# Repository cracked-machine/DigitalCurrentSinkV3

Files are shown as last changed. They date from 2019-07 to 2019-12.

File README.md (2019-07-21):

# Digital Current Sink Ver3

[Control Module Interactive BOM](https://cracked-machine.github.io/DigitalCurrentSinkV3/HW/ControlModule/doc/IBOM/ibom.html)

[Current Sink Module Interactive BOM](https://cracked-machine.github.io/DigitalCurrentSinkV3/HW/CurrentSinkModule/CurrentSinkModule/docs/IBOM/ibom.html)

[SMPS Module Interactive BOM](https://cracked-machine.github.io/DigitalCurrentSinkV3/HW/IsolatedThreeOutputSMPS/ExternRegulatedConverters/ExternRegulatedConverter_12D_12S_5S/docs/IBOM/ibom.html)

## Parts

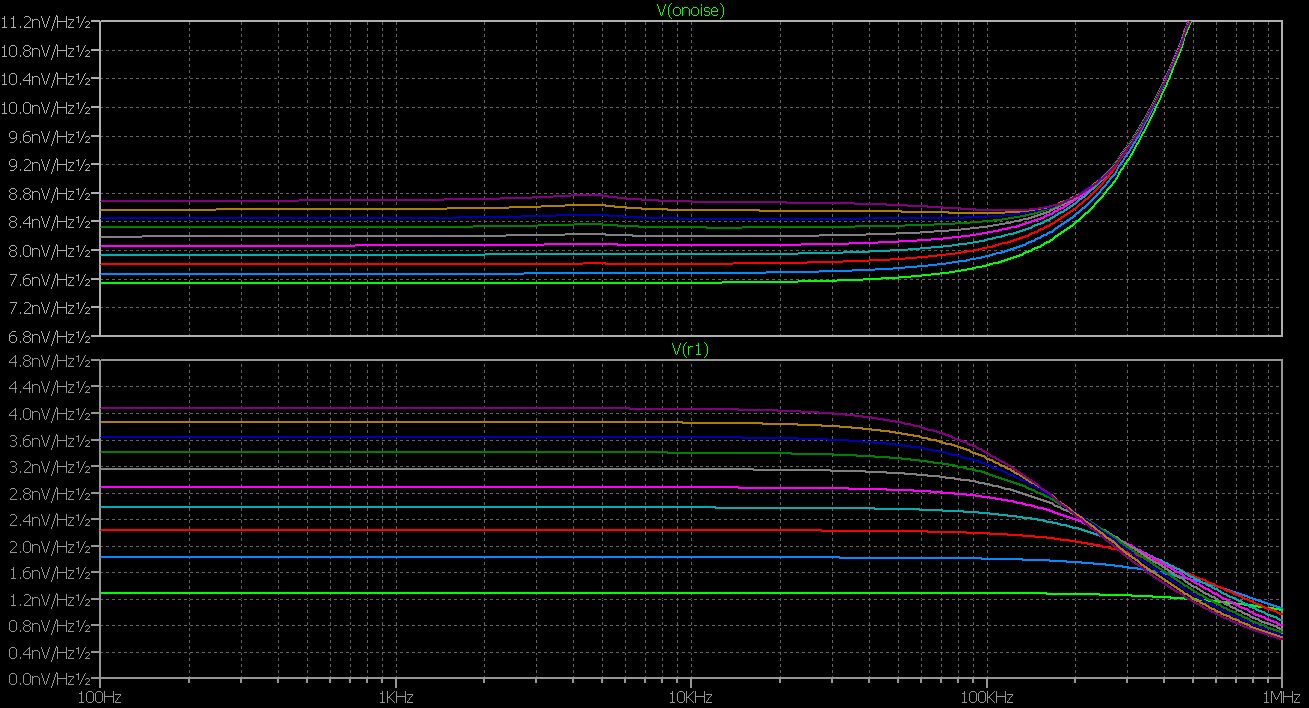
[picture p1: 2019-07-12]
HW/Simulation/ADA4522/FirstOrderSK_LowPass/1stOrderLowsPass_NoiseRange100R_1K.png

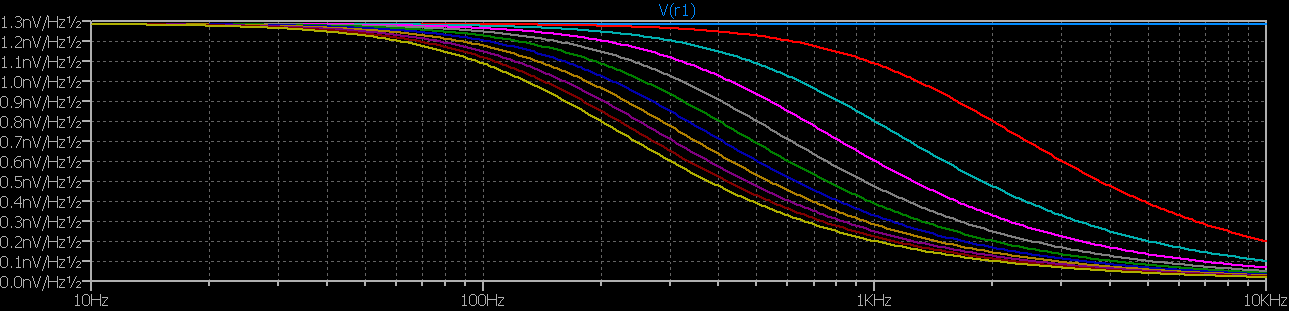
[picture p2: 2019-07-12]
HW/Simulation/ADA4522/FirstOrderSK_LowPass/1stOrderLowsPass_NoiseAndAttentuation100R_10u.png

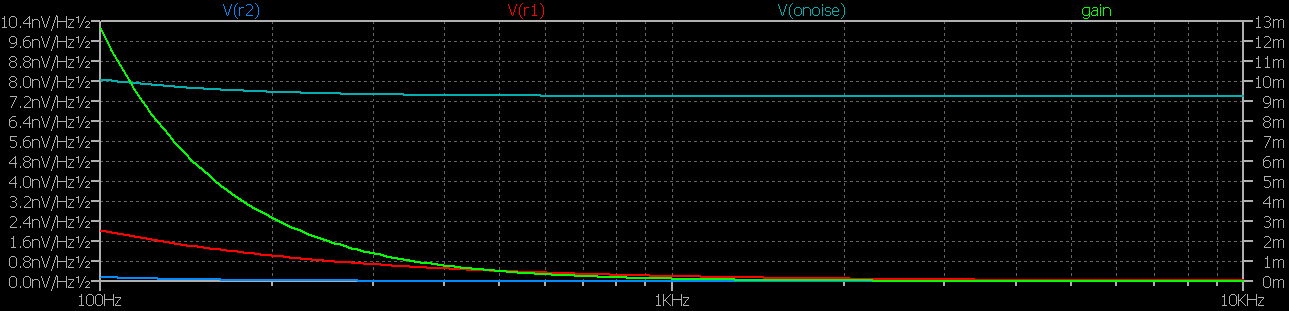
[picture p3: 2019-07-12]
HW/Simulation/ADA4522/SecondOrderSK_LowPass/2ndOrderSKLowPass_NoiseAndAtten_10K_1u.png

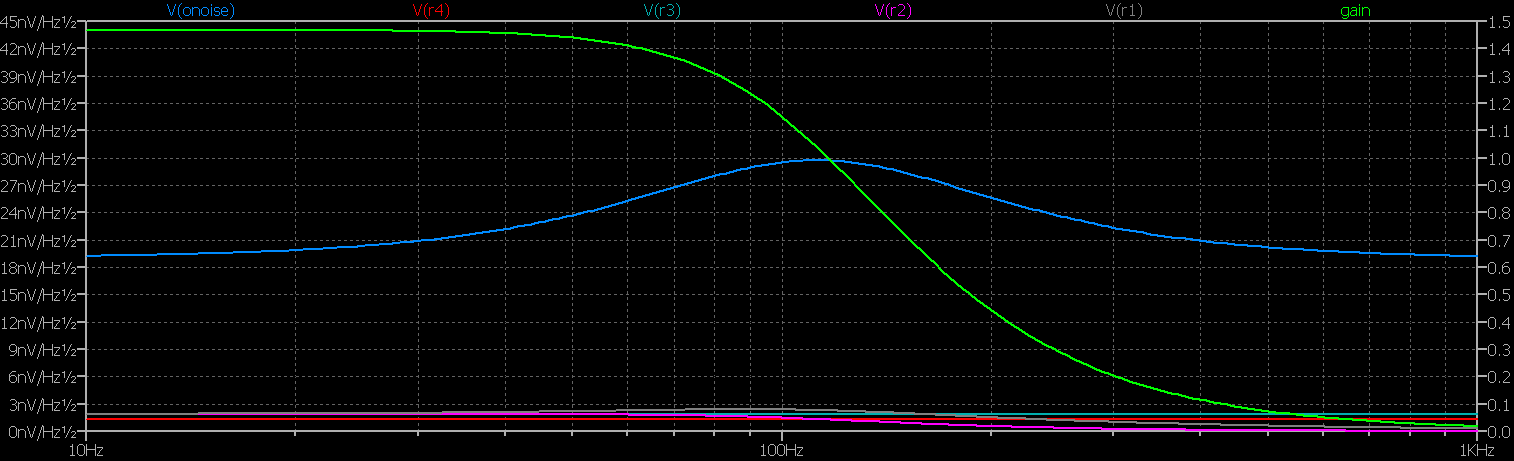
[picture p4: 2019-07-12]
HW/Simulation/LTC2058/2ndOrderSK_LowPassWithSeperateGainStage/2ndOrderLowsPass_SepStage1.5GainAndNoise2x100RWith10u_AndResistorNoiseContributions.png

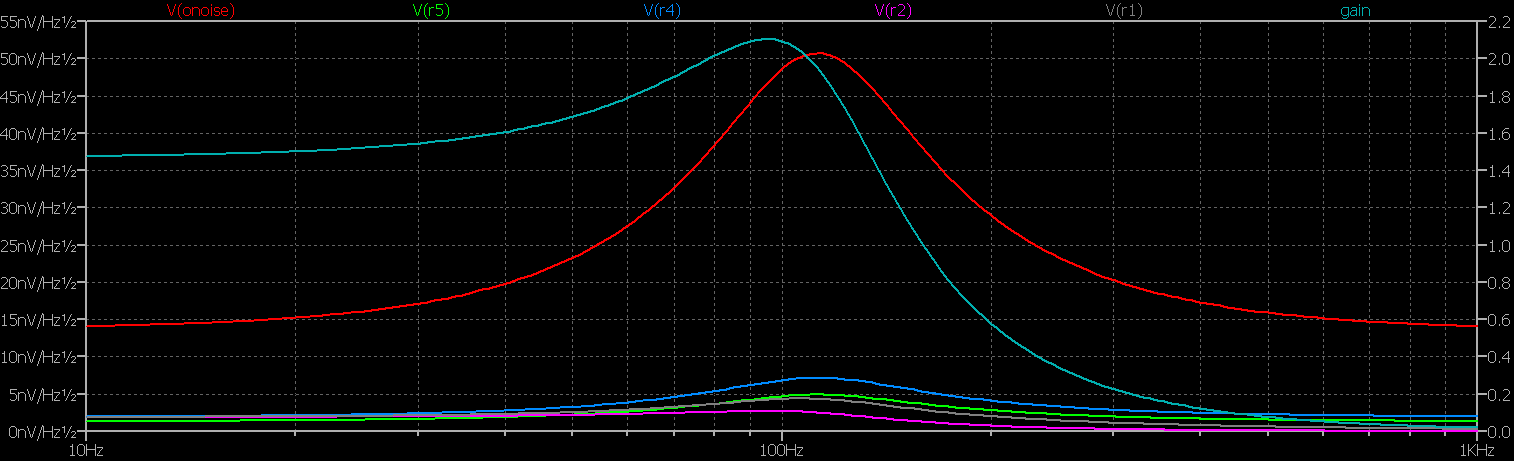
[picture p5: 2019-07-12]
HW/Simulation/LTC2058/SecondOrderSK_LowPass/2ndOrderLowsPass_1.5GainAndNoise2x100RWith10u_AndResistorNoiseContributions.png

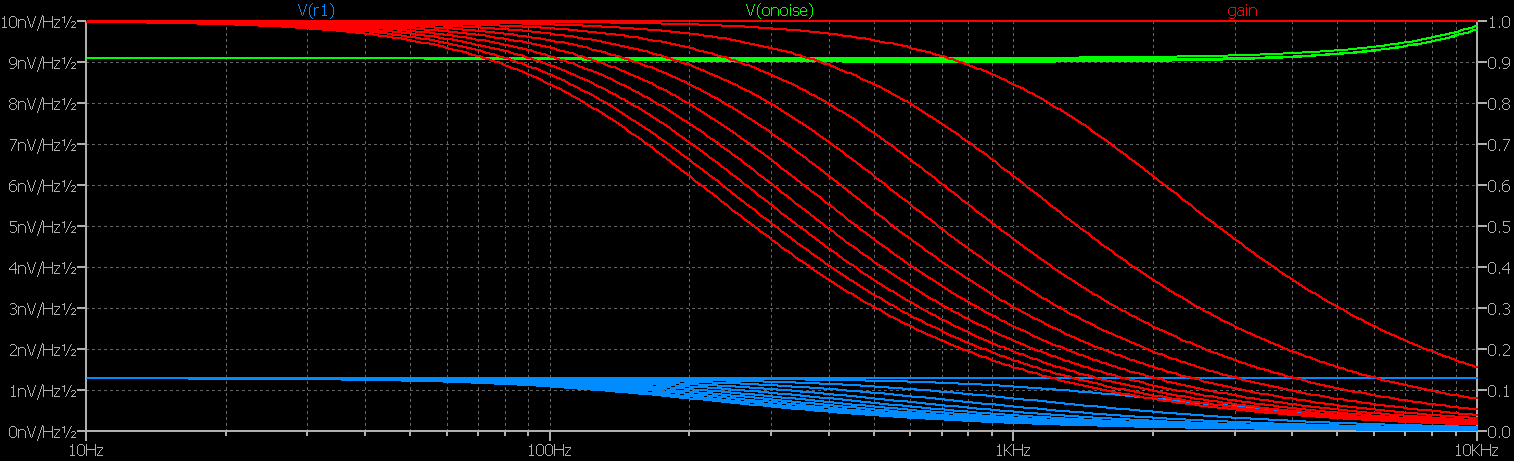
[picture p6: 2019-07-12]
HW/Simulation/LTC2058/FirstOrderSK_LowPass/1stOrderLowsPass_Noise100RWith0_10u.png

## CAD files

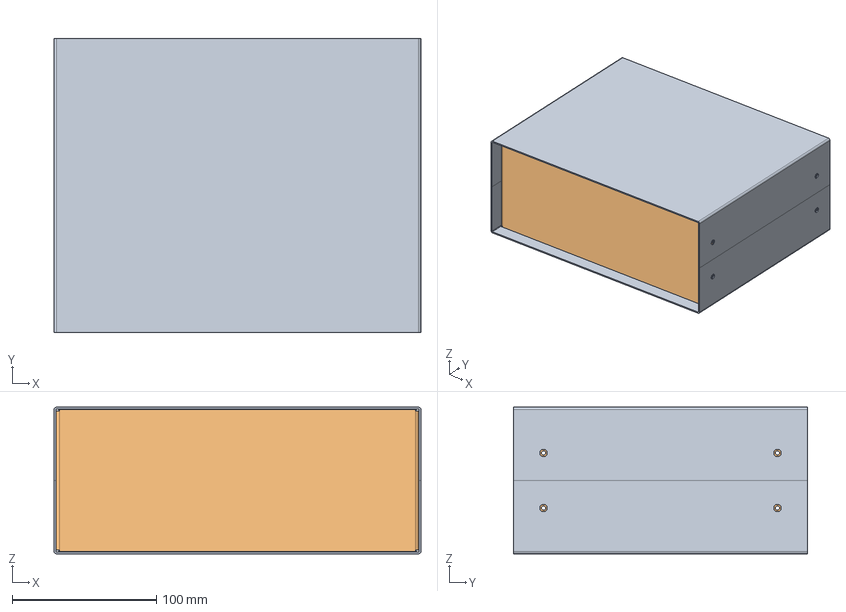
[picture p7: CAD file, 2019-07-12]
HW/Enclosure/1458G4.stp
254.0 x 203.2 x 101.6 mm

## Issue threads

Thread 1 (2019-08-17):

Molex Micro-Fit 3.0 connectors wired backwards on CurrentSink Module

cracked-machine, 2019-08-17:
For now the polarity can be switched for testing on the RevC board.

The connector footprint should be rotated 180deg on the RevD version.

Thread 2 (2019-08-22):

CurrentSink pcb heatsink "EndPlate" mounting holes should be replaced

cracked-machine, 2019-08-22:
Since the main heat-sink is to be reduced in length (100mm --> 75mm) the mounting holes on the currentsink pcb serve no purpose.

The new design is to use individual (two) heat-sinks for the complimentary MOSFETs.  Therefore, new mounting holes should be added to the currentsink pcb layout.  New heatsinks to be used are:

Fischer Elektronik SK 481/25 SA
https://docs-emea.rs-online.com/webdocs/0f3d/0900766b80f3d603.pdf

Requirements:
1) Each heatsink should have two mounting NPTH holes
2) There should be adequate clearance (air gap) from the other heatsinks to ensure electrical isolation
3) The heatsink should not touch any traces on the PCB. If necessary, traces should be moved to the other side of the PCB (see other issue)

cracked-machine, 2019-08-23:
Not required if issue #4 is implemented

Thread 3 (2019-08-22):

Move currentsink traces to back side of PCB to make room for heatsink

cracked-machine, 2019-08-22:
On currentsink layout, nets J4-Pad1 and J3_Pad3 should be moved from the front pcb side to the back pcb side. This will ensure that high current traces cannot come into accidental contact with heatsinks (see issue #2)

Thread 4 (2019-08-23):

Redesign current sink pcb for pmos/nmos to share single "LAM 3 K 75 12" heatsink

cracked-machine, 2019-08-23:
Current "SK 481/25 SA" heatsinks have 5.5K/W Rth each.
"LAM 3 K 75 12" heatsink has 1.1K/W.

Would also require moving the power connector "JPWR1"

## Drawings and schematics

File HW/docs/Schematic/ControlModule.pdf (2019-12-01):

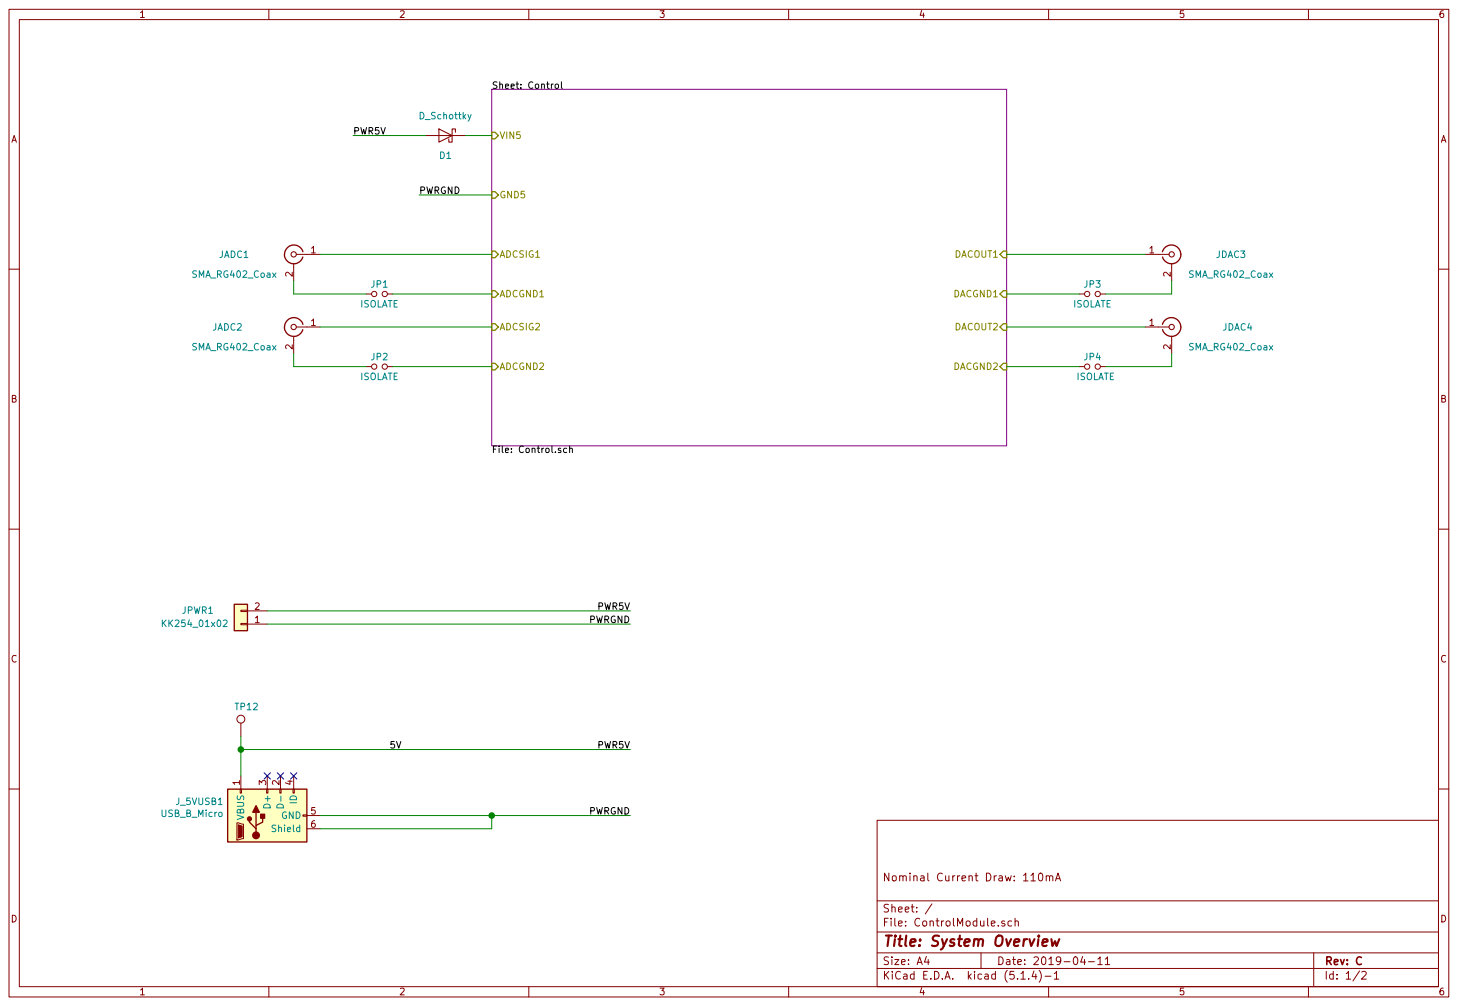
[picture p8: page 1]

File: ControlModule.sch Sheet: / Nominal Current Draw: 110mA

Id: 1/2 Title: System Overview

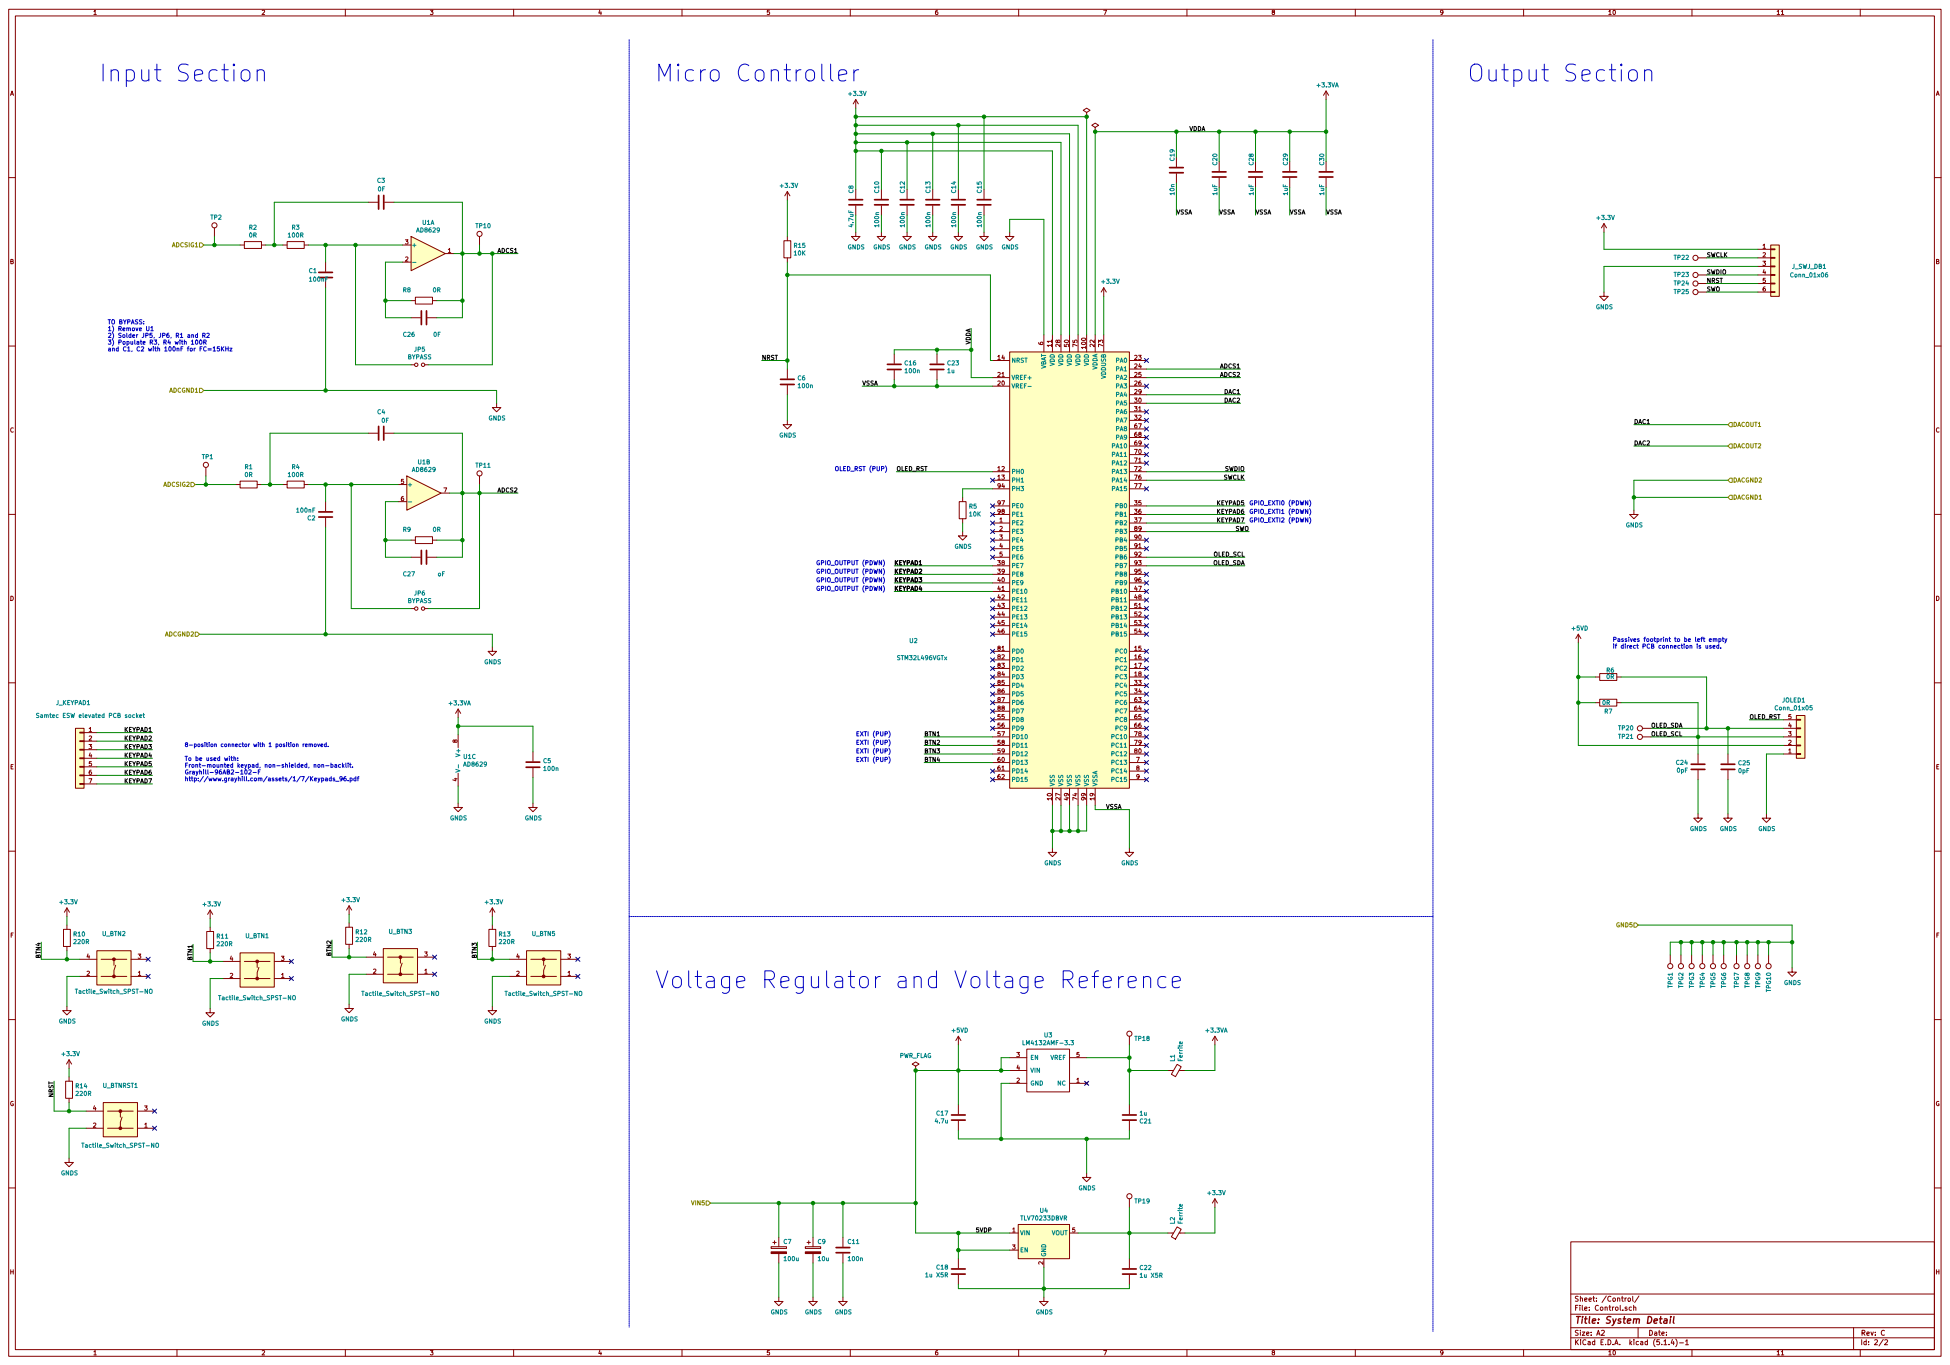
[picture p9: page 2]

6 VDD 100 VDD 11 VDD 28 VDD 50 VDD 75 VDDA 22 VDDUSB 73 VREF+ 21 VREF- 20 VSS 10 VSS 27 VSS 49 VSS 74 VSS 99 VSSA 19 U2 STM32L496VGTx

if direct PCB connection is used. Voltage Regulator and Voltage Reference

8-position connector with 1 position removed. To be used with: Front-mounted keypad, non-shielded, non-backlit.

Grayhill-96AB2-102-F
http://www.grayhill.com/assets/1/7/Keypads_96.pdf

Id: 2/2 Title: System Detail File: Control.sch Sheet: /Control/

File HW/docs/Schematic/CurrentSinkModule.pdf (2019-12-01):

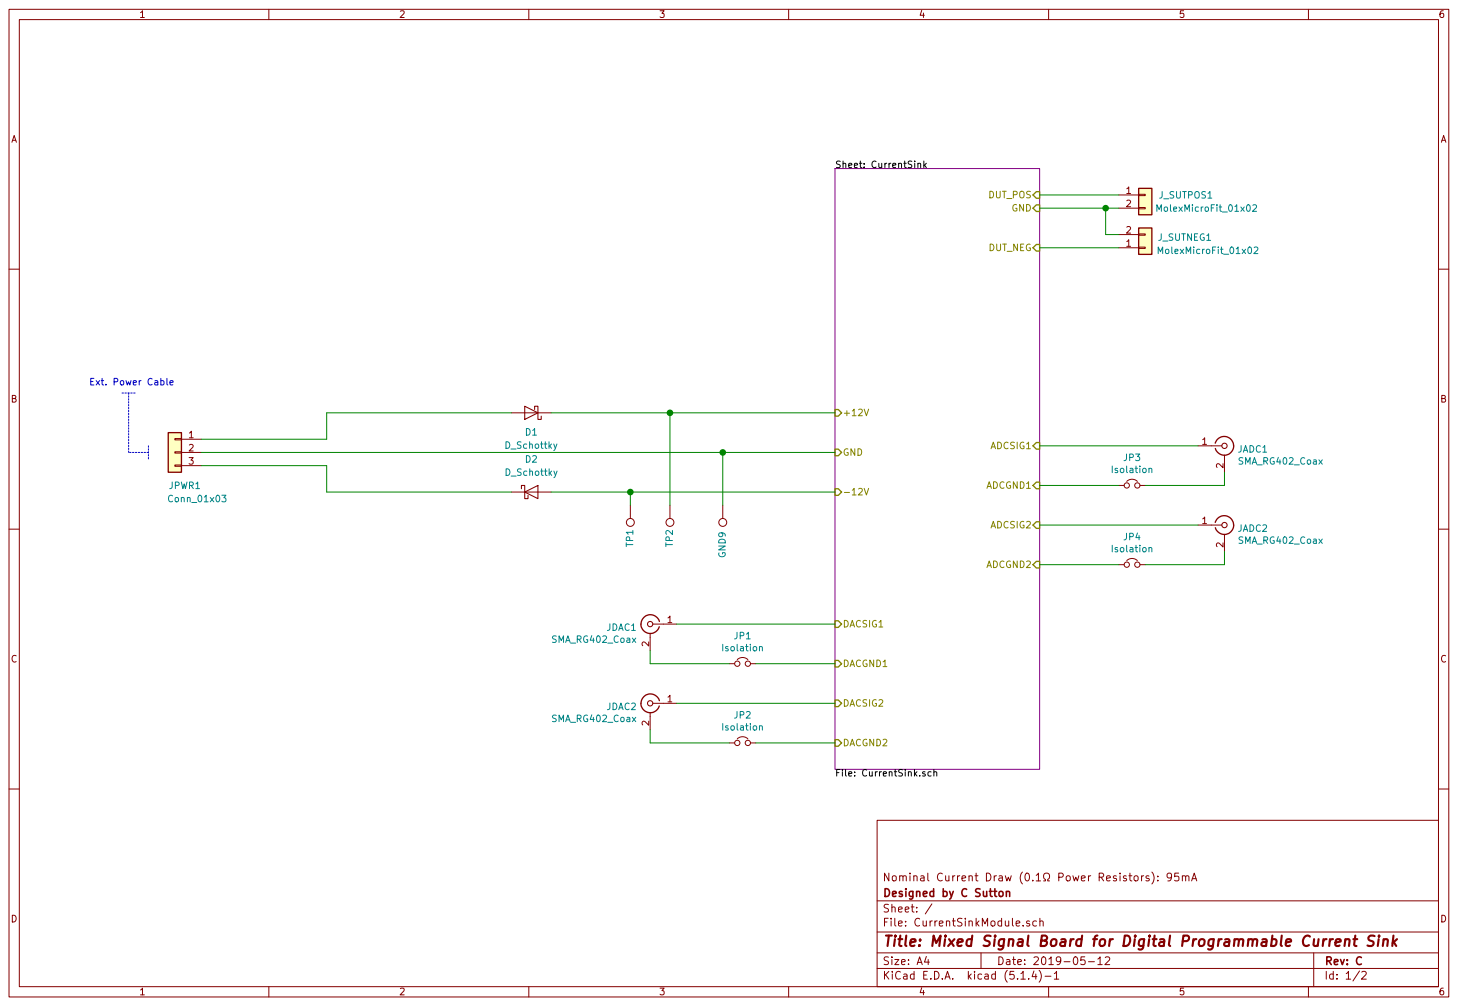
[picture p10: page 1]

ADCSIG2 ADCSIG1 ADCGND1 ADCGND2 DACSIG1 DACSIG2 DACGND1 DACGND2 +12V
File: CurrentSink.sch GND

Nominal Current Draw (0.1 Power Resistors): 95mA
File: CurrentSinkModule.sch Sheet: / Designed by C Sutton

Id: 1/2 Title: Mixed Signal Board for Digital Programmable Current Sink

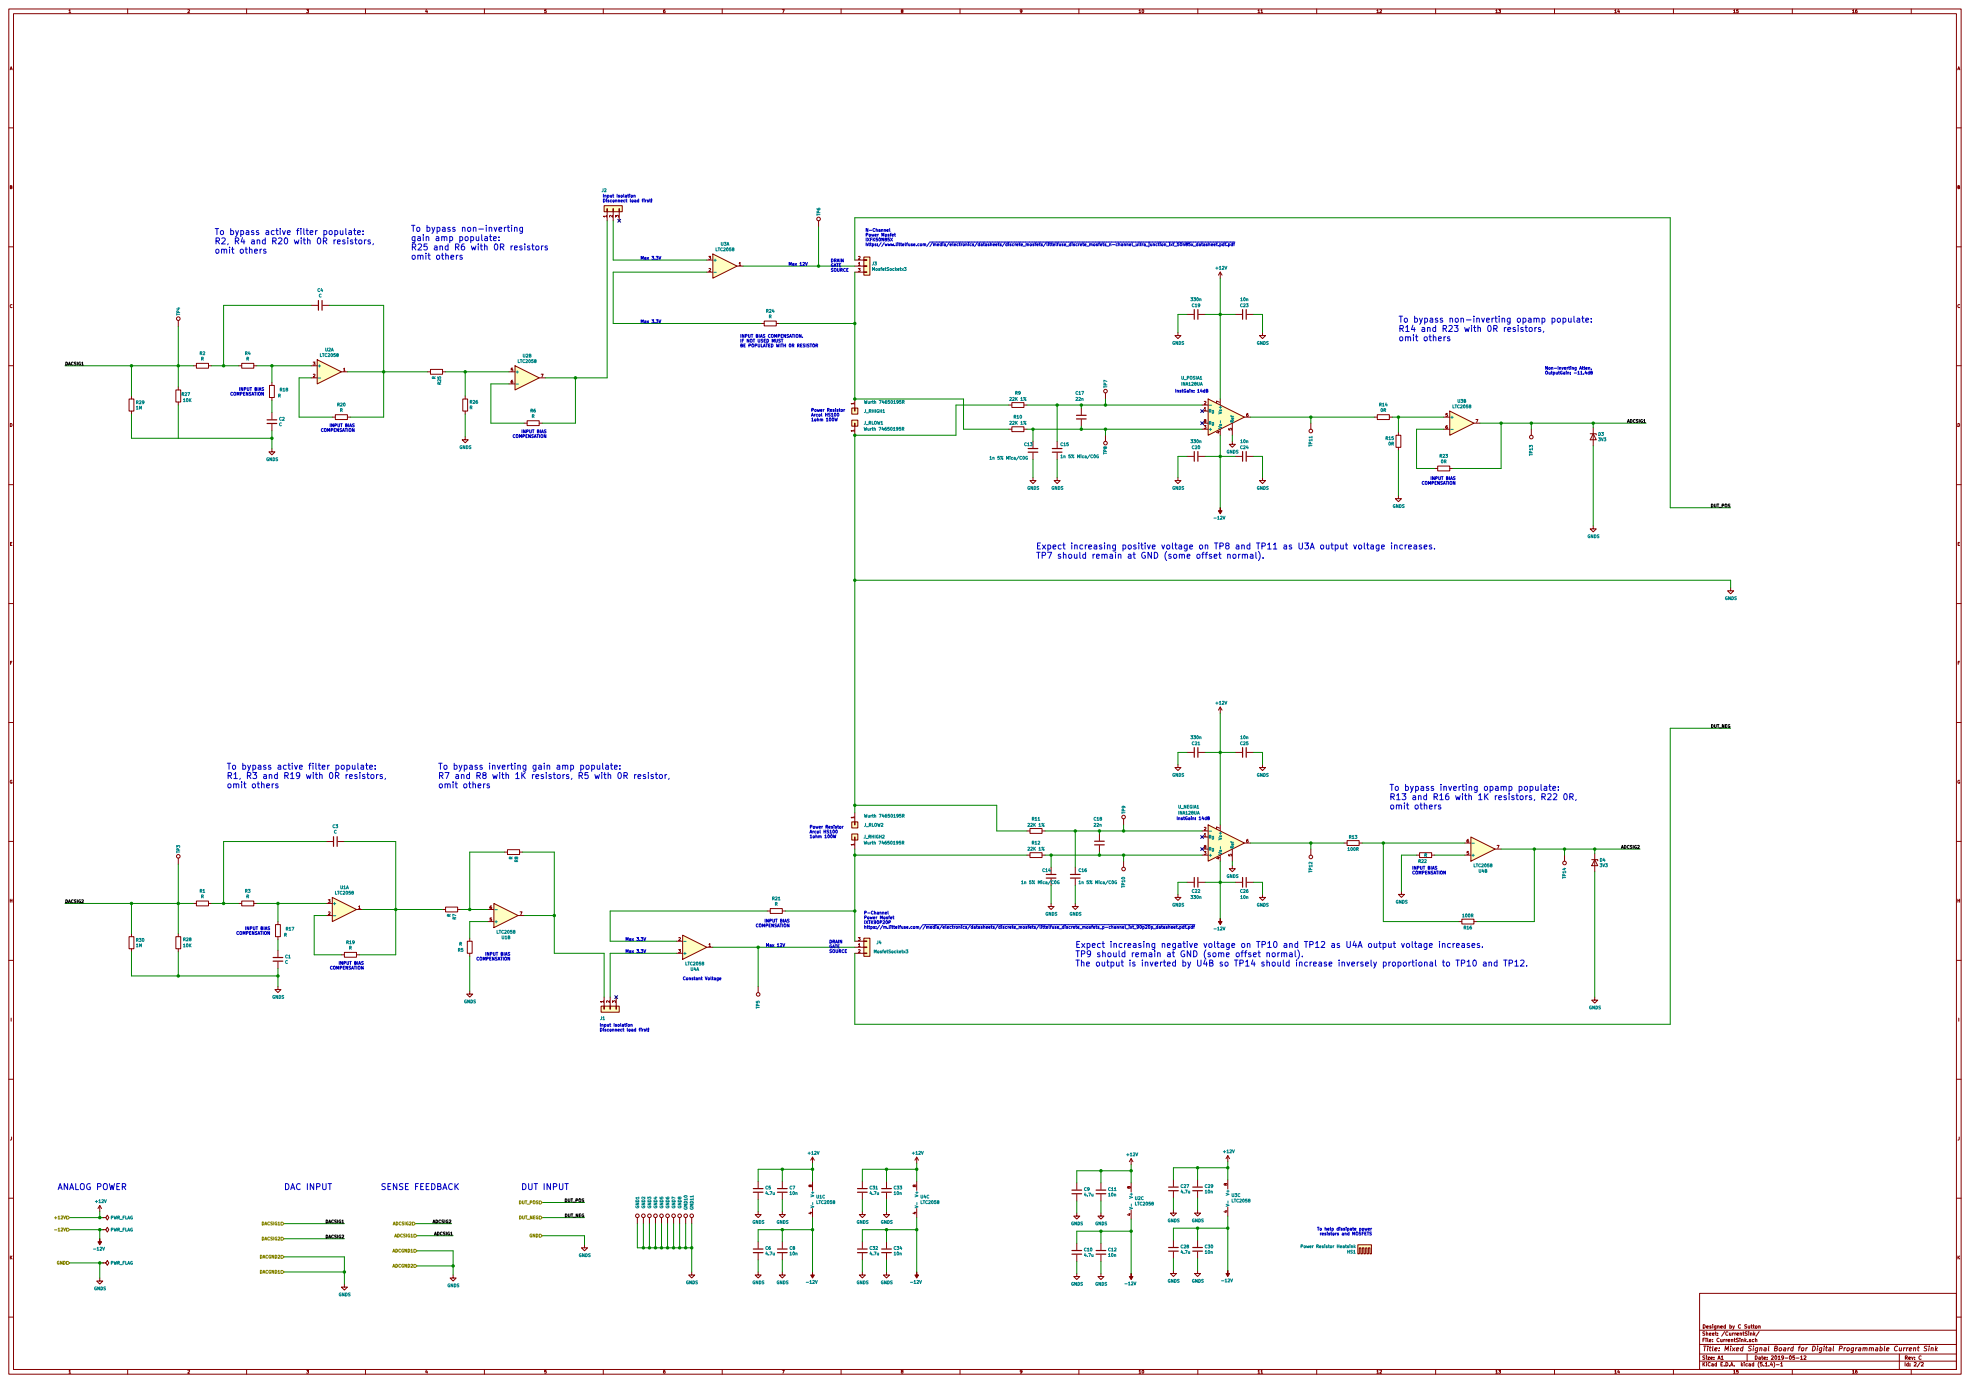
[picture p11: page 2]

Input Isolation Disconnect load first!

SOURCE To bypass active filter populate:
R2, R4 and R20 with 0R resistors,
omit others

To bypass non-inverting
gain amp populate:
R25 and R6 with 0R resistors

https://www.littelfuse.com//media/electronics/datasheets/discrete_mosfets/littelfuse_discrete_mosfets_n-channel_ultra_junction_ixf_50n85x_datasheet.pdf.pdf Power Resistor Arcol HS100 1ohm 100W

To bypass non-inverting opamp populate:
R14 and R23 with 0R resistors,

INPUT BIAS COMPENSATION.
IF NOT USED MUST BE POPULATED WITH 0R RESISTOR

File: CurrentSink.sch Sheet: /CurrentSink/ Designed by C Sutton TP8 C17

TP7 should remain at GND (some offset normal).

To bypass active filter populate:
R1, R3 and R19 with 0R resistors,

To bypass inverting gain amp populate:
R7 and R8 with 1K resistors, R5 with 0R resistor,

To bypass inverting opamp populate:
R13 and R16 with 1K resistors, R22 0R,

https://m.littelfuse.com//media/electronics/datasheets/discrete_mosfets/littelfuse_discrete_mosfets_p-channel_ixt_90p20p_datasheet.pdf.pdf Max 12V Max 3.3V Max 3.3V

Expect increasing negative voltage on TP10 and TP12 as U4A output voltage increases.
TP9 should remain at GND (some offset normal).
The output is inverted by U4B so TP14 should increase inversely proportional to TP10 and TP12.

To help dissipate power
resistors and MOSFETS

Id: 2/2 Title: Mixed Signal Board for Digital Programmable Current Sink

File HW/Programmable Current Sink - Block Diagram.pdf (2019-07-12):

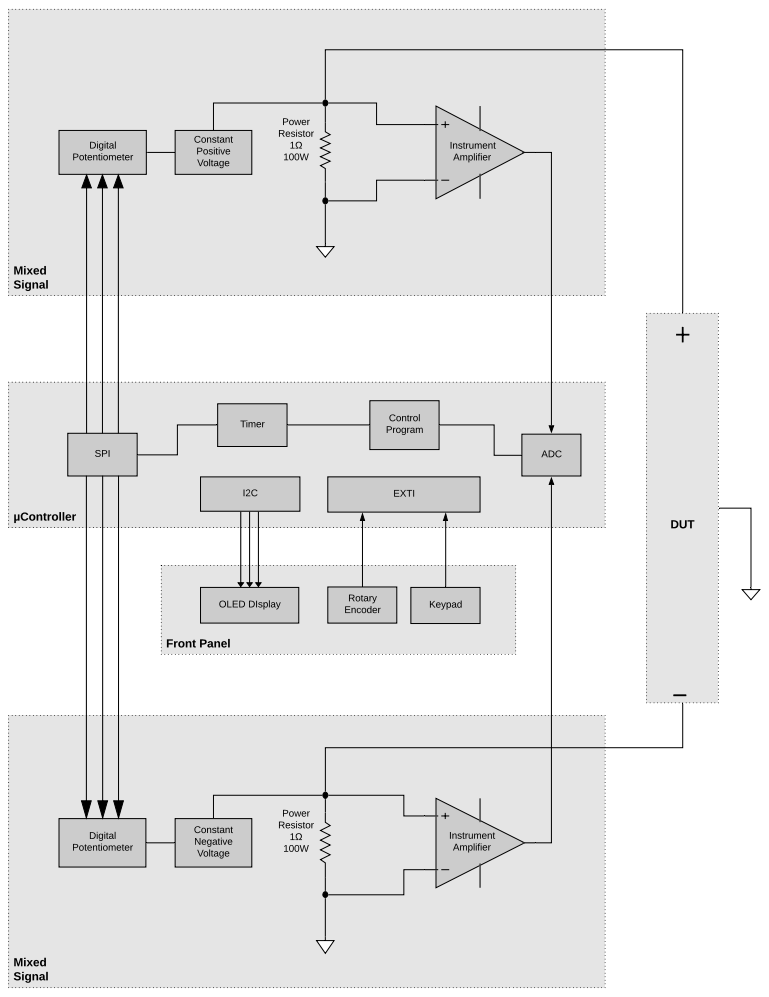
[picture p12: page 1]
Front Panel; Mixed Signal; DUT; µController; SPI; ADC; Timer; Control Program; Digital Potentiometer; Constant Negative Voltage; Power Resistor 1? 100W; Instrument Amplifier; Constant Positive Voltage; OLED DIsplay; EXTI; Rotary Encoder; Keypad

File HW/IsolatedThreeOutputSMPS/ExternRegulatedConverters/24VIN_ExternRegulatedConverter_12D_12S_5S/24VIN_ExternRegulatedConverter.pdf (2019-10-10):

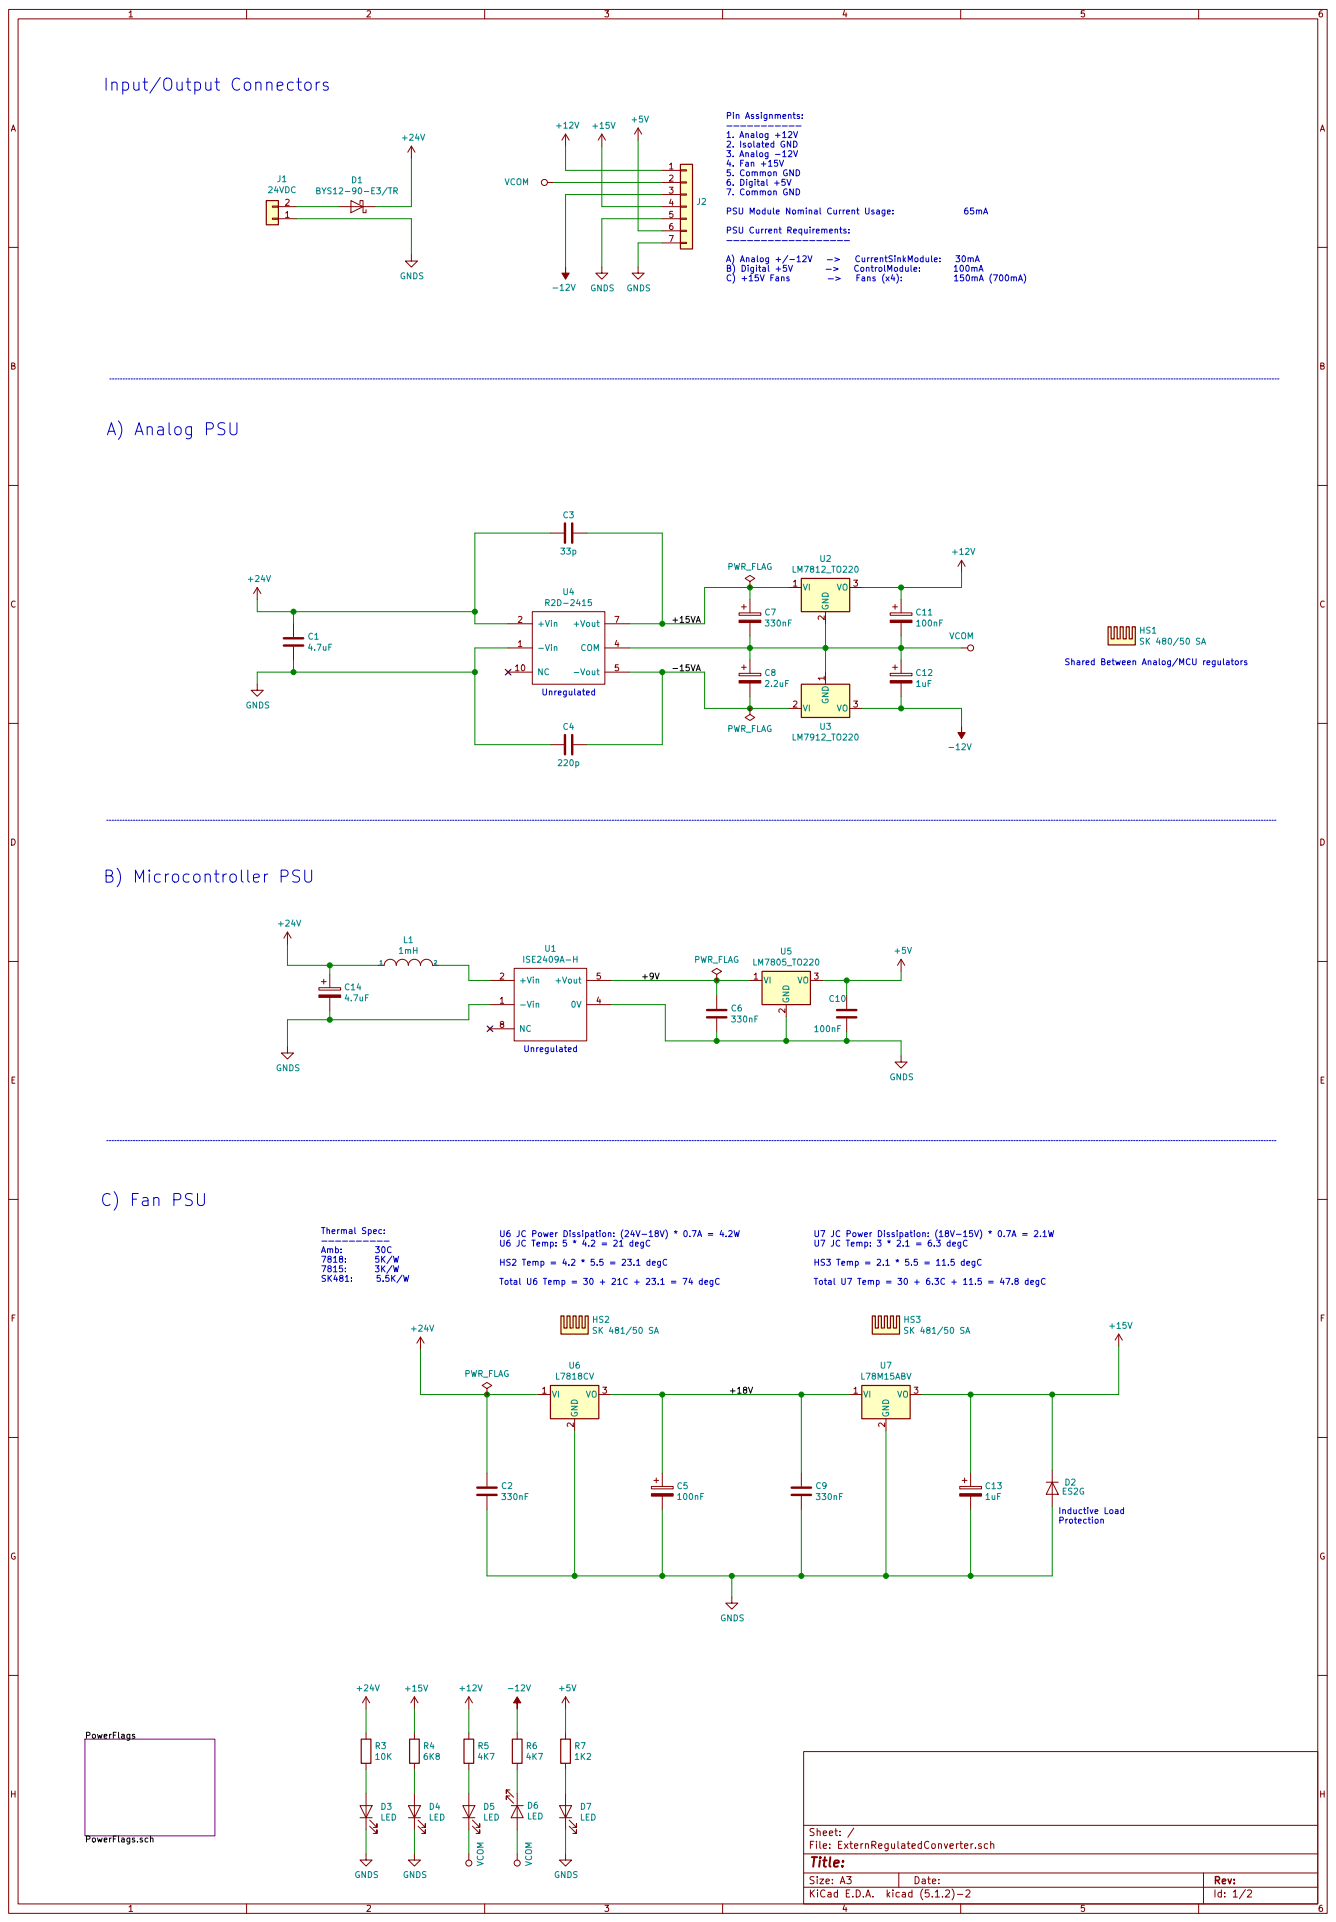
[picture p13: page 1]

Shared Between Analog/MCU regulators

HS3SK 481/50 SA U6 JC Power Dissipation: (24V-18V) * 0.7A = 4.2W
U6 JC Temp: 5 * 4.2 = 21 degC
HS2 Temp = 4.2 * 5.5 = 23.1 degC
Total U6 Temp = 30 + 21C + 23.1 = 74 degC

File: ExternRegulatedConverter.sch Sheet: /

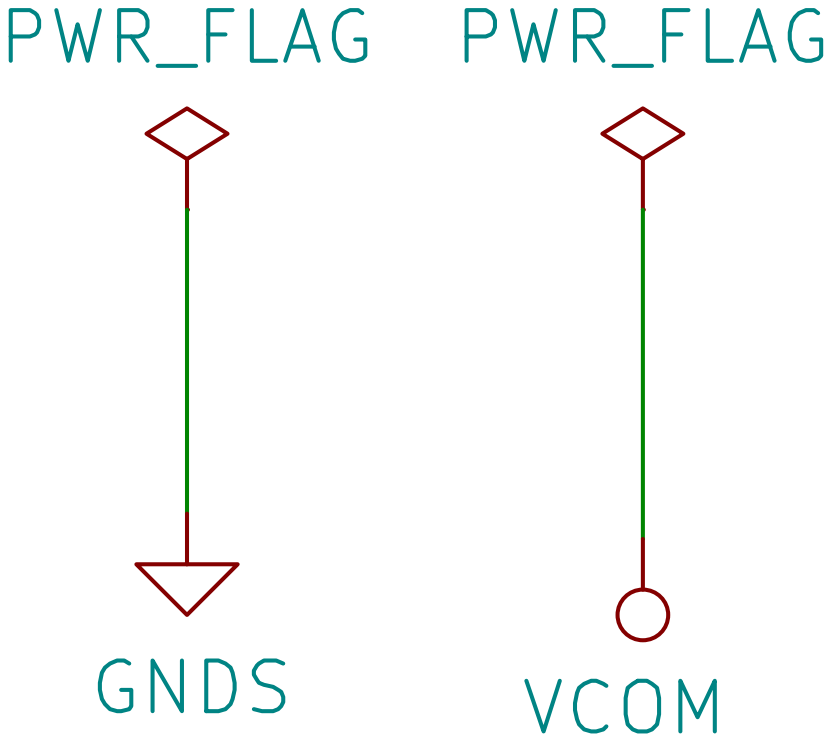
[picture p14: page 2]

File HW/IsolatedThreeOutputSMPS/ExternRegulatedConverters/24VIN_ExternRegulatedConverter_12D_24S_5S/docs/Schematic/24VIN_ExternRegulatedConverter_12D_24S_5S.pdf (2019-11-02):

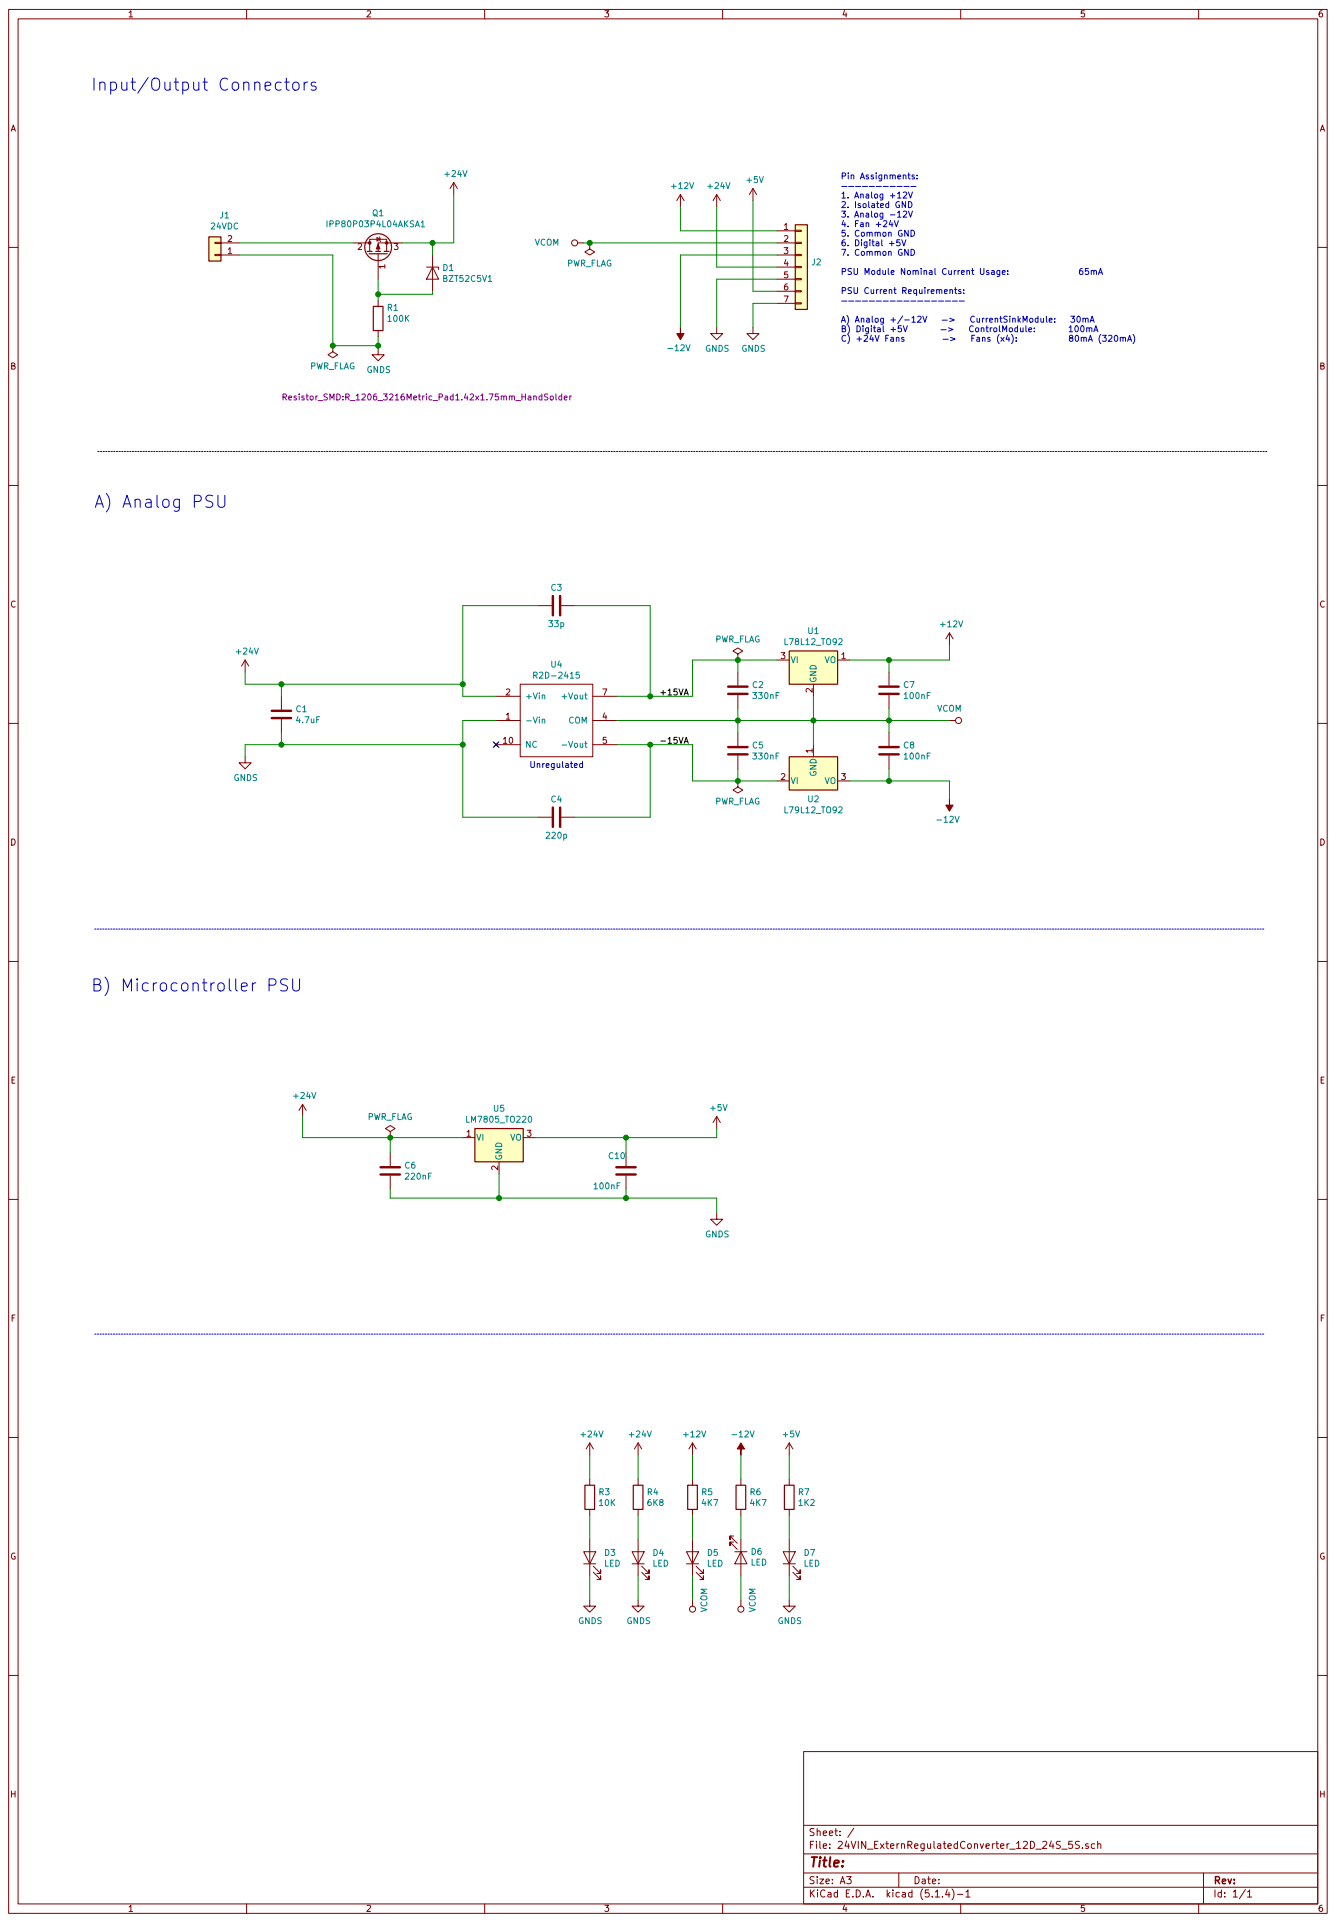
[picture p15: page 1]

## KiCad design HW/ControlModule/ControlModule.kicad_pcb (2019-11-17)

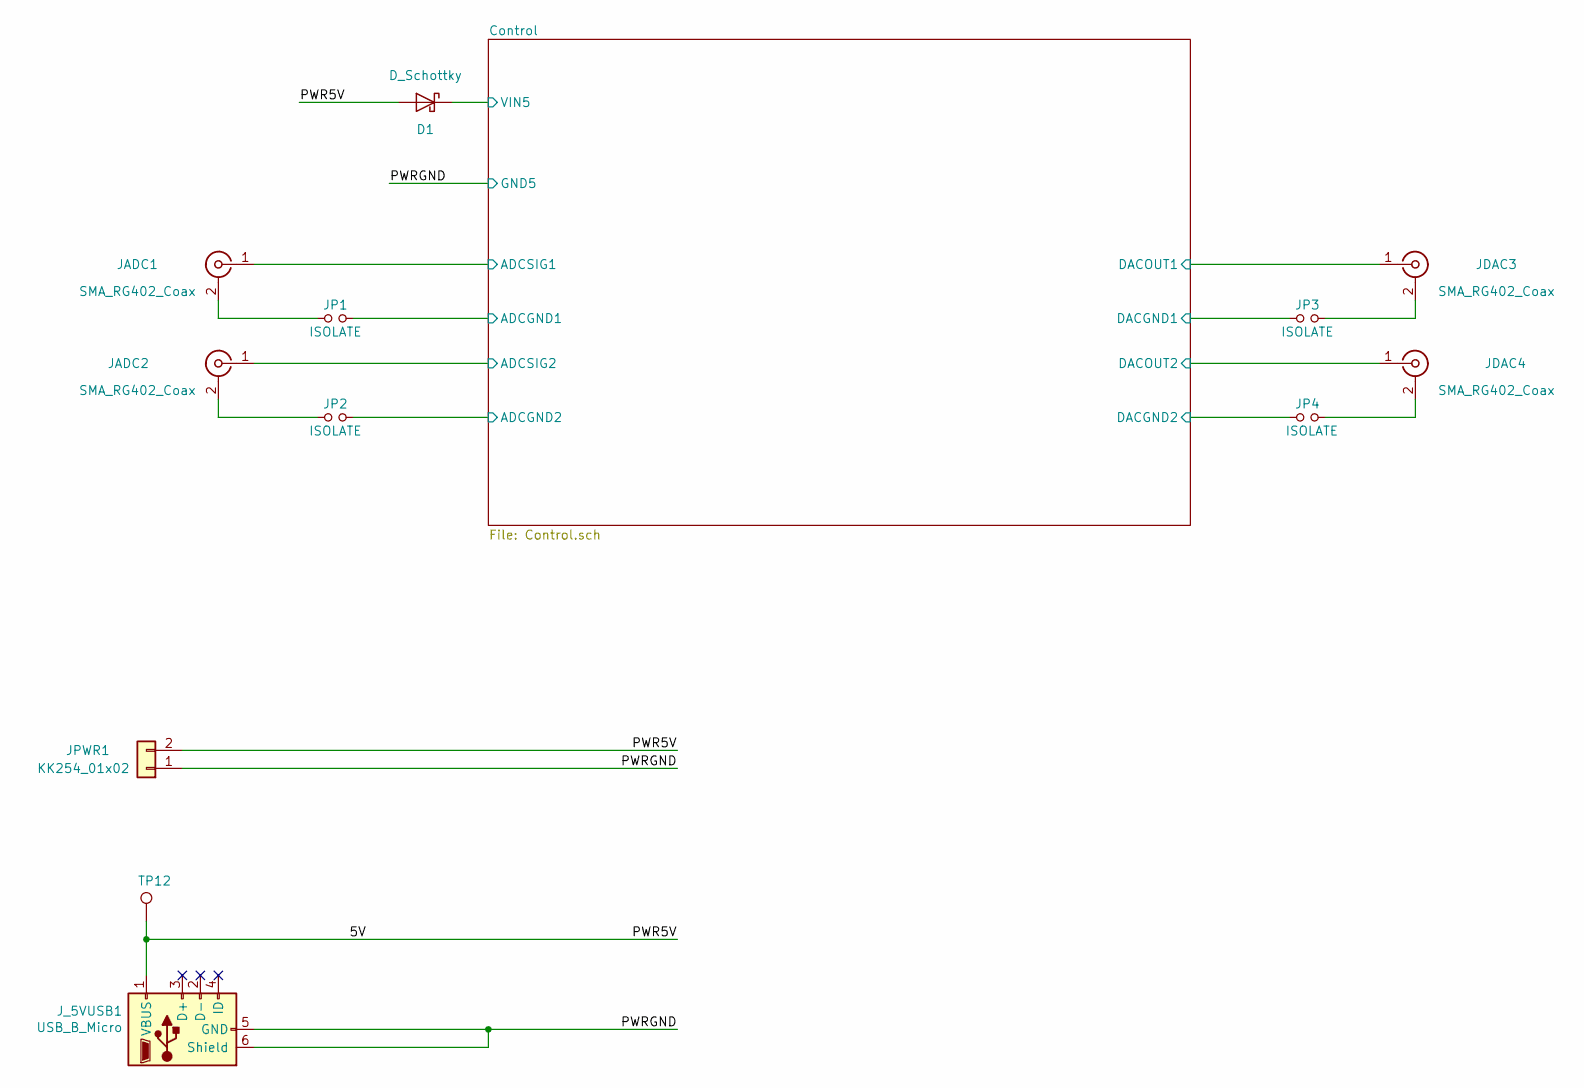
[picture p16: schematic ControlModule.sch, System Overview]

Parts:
D1: D_Schottky; D_SMA_Handsoldering; DigikeyNo SS110FL-TPMSTR-ND
JADC1, JADC2: SMA_RG402_Coax; SMA_Amphenol_901-144_Vertical; MouserNo 571-5-1814832-1
JDAC3, JDAC4: SMA_RG402_Coax; SMA_Amphenol_901-144_Vertical; MouserNo 571-5-1814832-1
JP1, JP2, JP3, JP4: ISOLATE; SolderJumper-2_P1.3mm_Bridged_Pad1.0x1.5mm
JPWR1: KK254_01x02; Molex_KK-254_AE-6410-02A_1x02_P2.54mm_Vertical
J_5VUSB1: USB_B_Micro; USB_Micro-B_Amphenol_10103594-0001LF_Horizontal; DigikeyNo 609-4050-2-ND
TP12: TestPoint; TestPoint_Pad_2.0x2.0mm; MouserNo 855-S2751-46R

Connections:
+5VD: D1.1 (K); also elsewhere on the board
/5V: D1.2 (A), JPWR1.2, J_5VUSB1.1 (VBUS), TP12.1
/Control/ADCSIG1: JADC1.1 (In); also elsewhere on the board
/Control/ADCSIG2: JADC2.1 (In); also elsewhere on the board
/Control/DACOUT1: JDAC3.1 (In); also elsewhere on the board
/Control/DACOUT2: JDAC4.1 (In); also elsewhere on the board
GNDS: JP1.2, JP2.2, JP3.1, JP4.1, JPWR1.1, J_5VUSB1.5 (GND), J_5VUSB1.6 (Shield); also elsewhere on the board
unnamed: JADC1.2 (Ext), JP1.1
unnamed: JADC2.2 (Ext), JP2.1
unnamed: JDAC3.2 (Ext), JP3.2
unnamed: JDAC4.2 (Ext), JP4.2

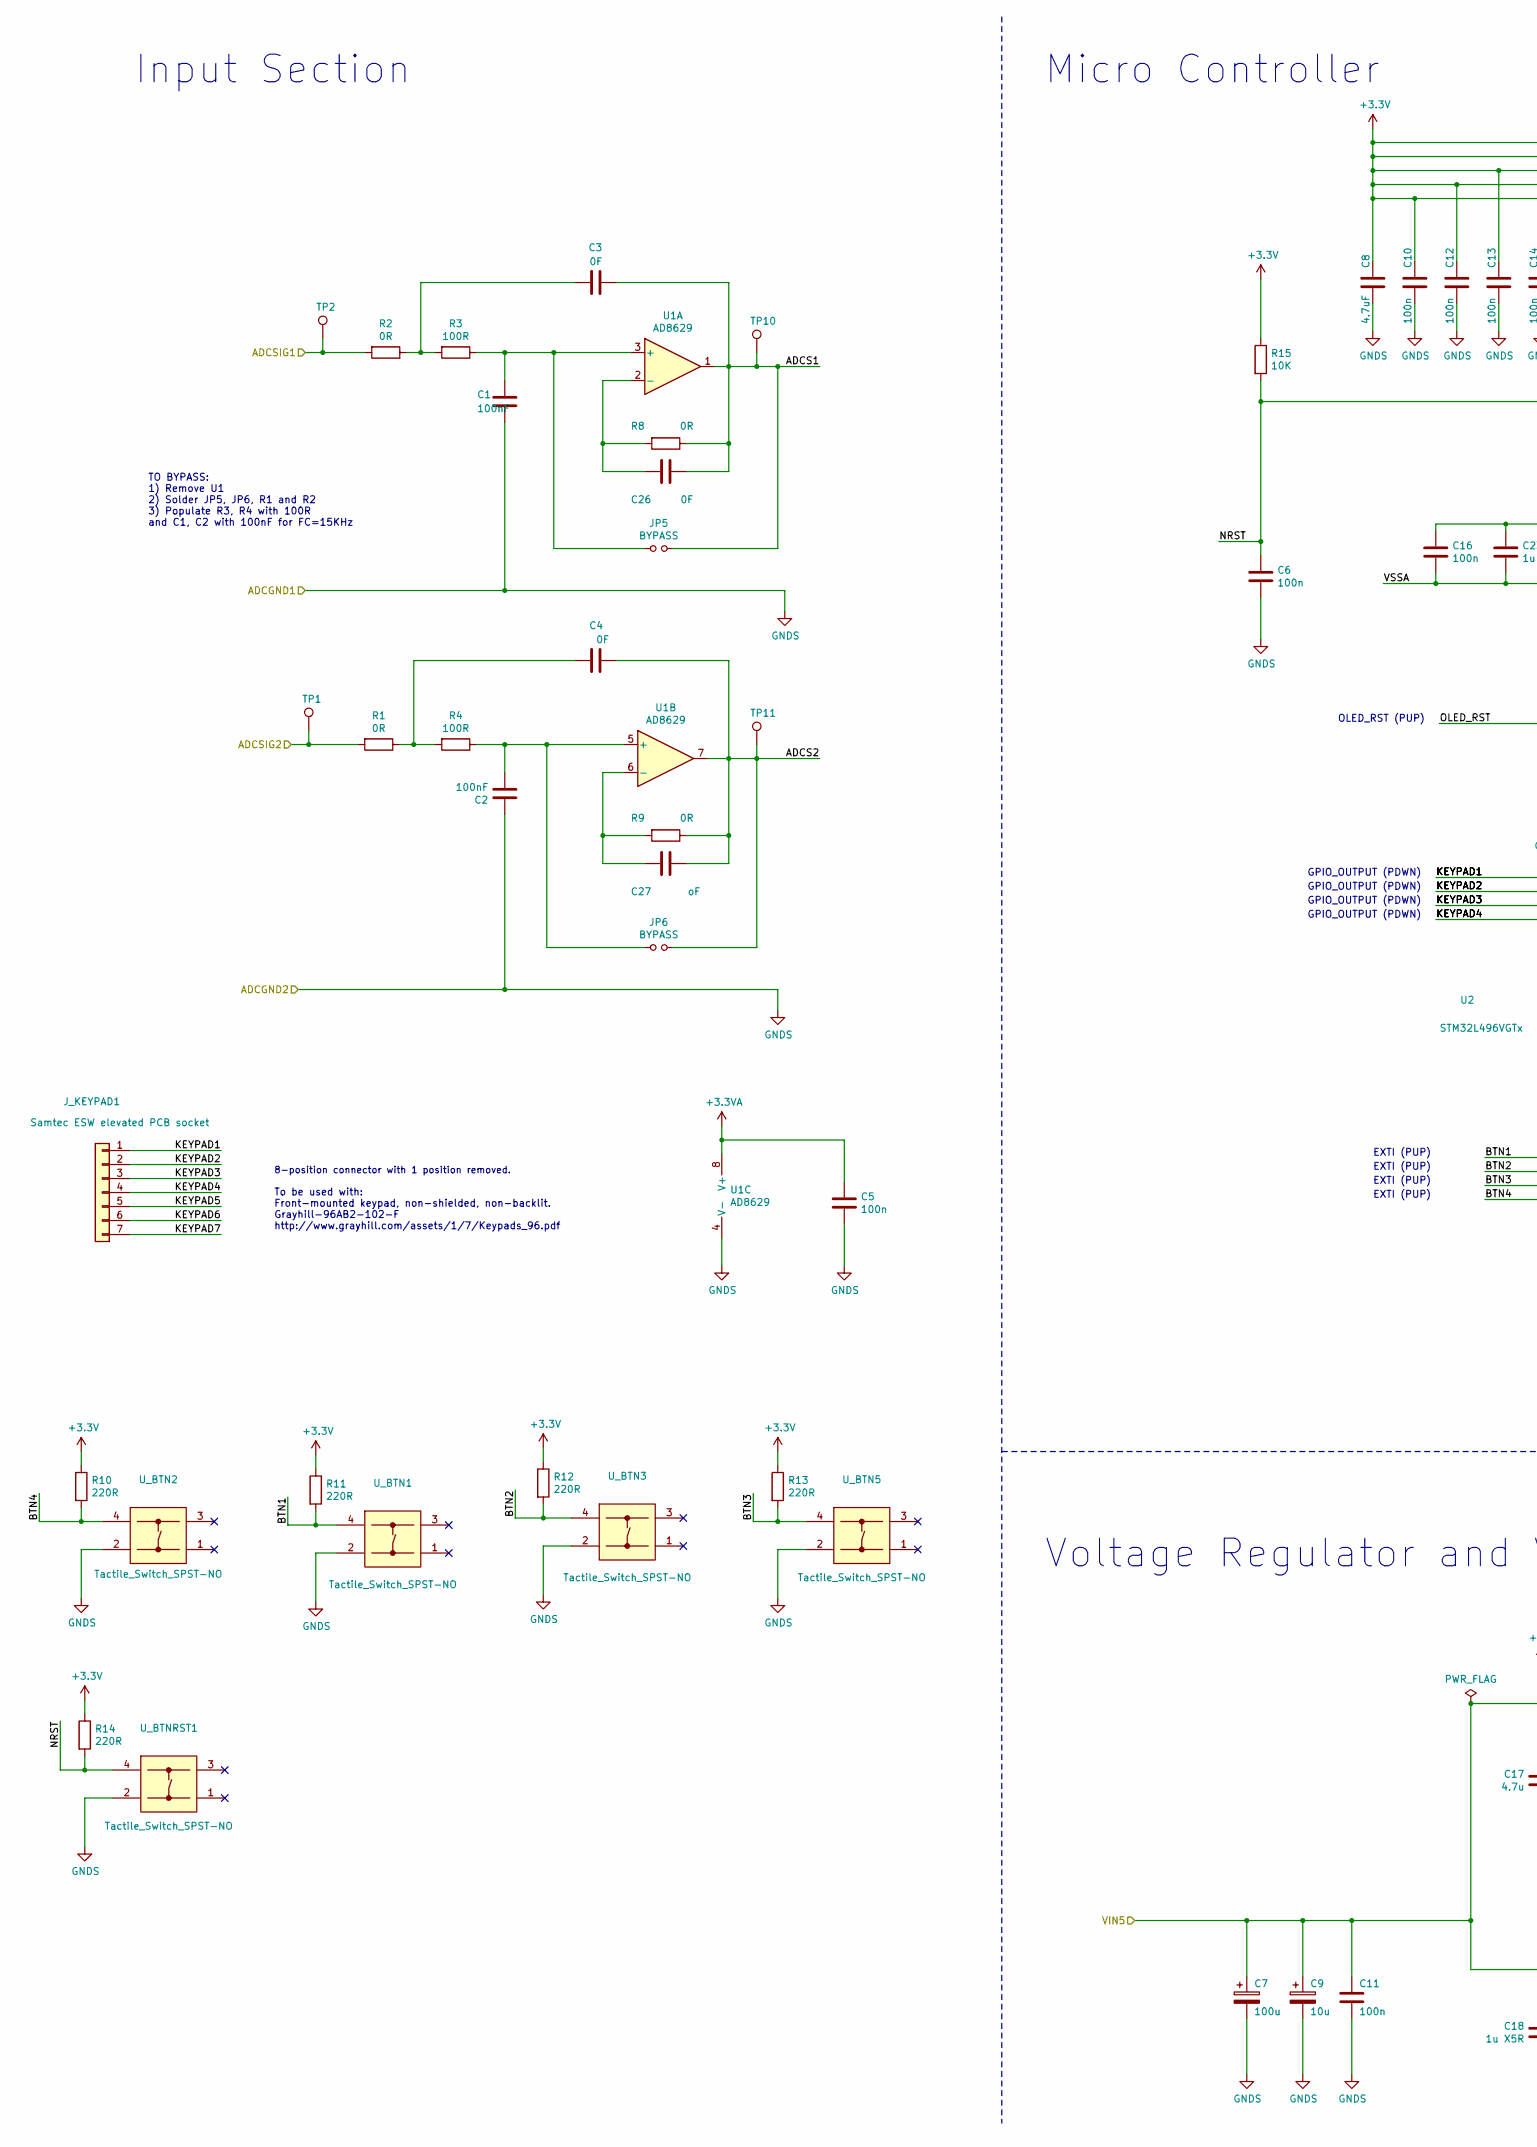
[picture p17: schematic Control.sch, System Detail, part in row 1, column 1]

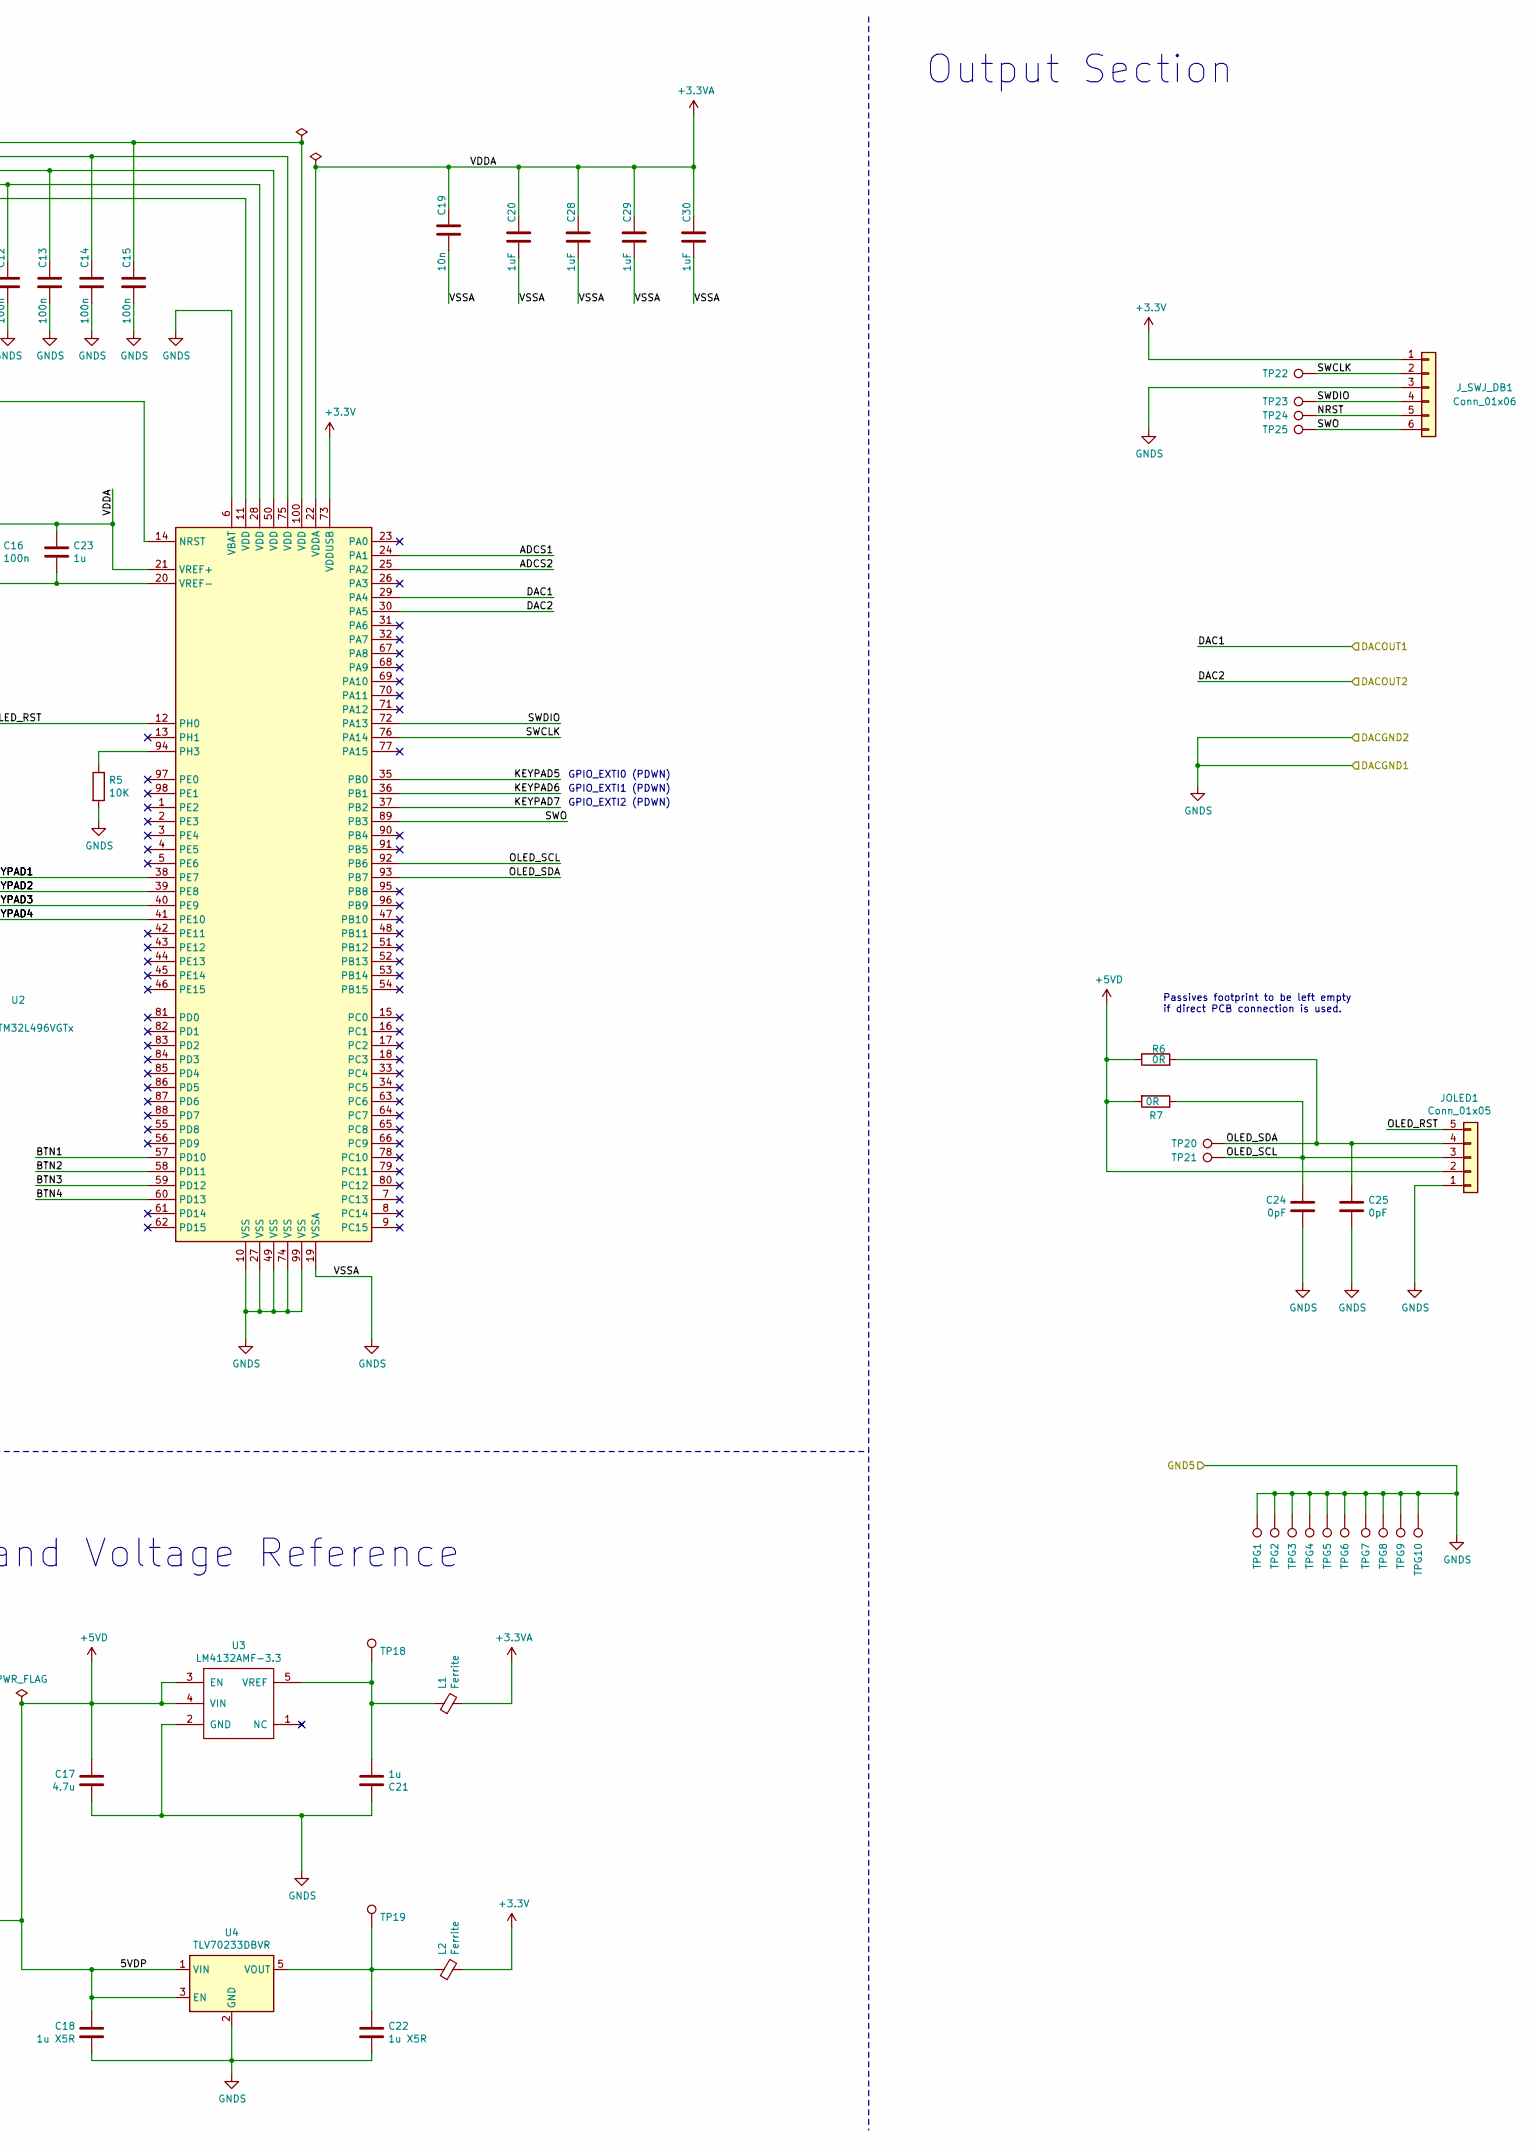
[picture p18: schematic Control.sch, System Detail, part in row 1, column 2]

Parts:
C1, C2: 100nF; C_0805_2012Metric_Pad1.15x1.40mm_HandSolder
C3, C4, C26: 0F; C_0805_2012Metric_Pad1.15x1.40mm_HandSolder
C5, C6, C10, C12, C13, C14, C15, C16: 100n; C_0402_1005Metric
C7: 100u; CP_Elec_5x3.9
C8: 4.7uF; C_0402_1005Metric
C9: 10u; CP_Elec_5x3.9
C11: 100n; C_0805_2012Metric_Pad1.15x1.40mm_HandSolder
C17: 4.7u; C_0805_2012Metric_Pad1.15x1.40mm_HandSolder
C18, C22: 1u X5R; C_0805_2012Metric_Pad1.15x1.40mm_HandSolder
C19: 10n; C_0402_1005Metric
C20, C28, C29, C30: 1uF; C_0402_1005Metric
C21: 1u; C_0805_2012Metric_Pad1.15x1.40mm_HandSolder
C23: 1u; C_0402_1005Metric
C24, C25: 0pF; C_0805_2012Metric_Pad1.15x1.40mm_HandSolder
C27: oF; C_0805_2012Metric_Pad1.15x1.40mm_HandSolder
JOLED1: Conn_01x05; DIYMORE_SSD1309
JP5, JP6: BYPASS; SolderJumper-2_P1.3mm_Bridged_Pad1.0x1.5mm
J_KEYPAD1: Samtec ESW elevated PCB socket; PinSocket_1x07_P2.54mm_Vertical; MouserNo 200-ESW10812TS
J_SWJ_DB1: Conn_01x06; PinHeader_1x06_P2.54mm_Vertical
L1, L2: Ferrite; R_0805_2012Metric_Pad1.15x1.40mm_HandSolder
R1, R2, R6, R7, R8, R9: 0R; R_0805_2012Metric_Pad1.15x1.40mm_HandSolder
R3, R4: 100R; R_0805_2012Metric_Pad1.15x1.40mm_HandSolder
R5: 10K; R_0402_1005Metric
R10, R11, R12, R13, R14: 220R; R_0805_2012Metric_Pad1.15x1.40mm_HandSolder
R15: 10K; R_0805_2012Metric_Pad1.15x1.40mm_HandSolder
TP1, TP2, TP10, TP11, TP18, TP19: TestPoint; TestPoint_Pad_2.0x2.0mm; MouserNo 855-S2751-46R
TP20, TP21, TP22, TP23, TP24, TP25: TestPoint; TestPoint_Pad_2.0x2.0mm
TPG1, TPG2, TPG3, TPG4, TPG5, TPG6, TPG7, TPG8, TPG9, TPG10: TestPoint; TestPoint_Pad_2.0x2.0mm; MouserNo 855-S2751-46R
U1: AD8629; SOIC-8_3.9x4.9mm_P1.27mm; MouserNo 584-AD8629ARZ-R7
U2: STM32L496VGTx; LQFP-100_14x14mm_P0.5mm
U3: LM4132AMF-3.3; SOT-23-5_HandSoldering; DigikeyNo LM4132AMF-3.3/NOPBCT-ND
U4: TLV70233DBVR; SOT-23-5; MouserNo 595-TLV70233DBVR
U_BTN1: Tactile_Switch_SPST-NO; 12x12x7_3mmTactilePushButtonMomentary; MouserNo 653-B3F-5050
U_BTN2, U_BTN3, U_BTN5: Tactile_Switch_SPST-NO; 12x12x7_3mmTactilePushButtonMomentary
U_BTNRST1: Tactile_Switch_SPST-NO; 12x12x7_3mmTactilePushButtonMomentary

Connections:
+3.3VA: C5.1, C16.1, C19.1, C20.1, C23.1, C28.1, C29.1, C30.1, L1.2, U1.8 (V+), U2.21 (VREF+), U2.22 (VDDA)
+3V3: C8.1, C10.1, C12.1, C13.1, C14.1, C15.1, J_SWJ_DB1.1, L2.2, R10.1, R11.1, R12.1, R13.1, R14.1, R15.1, U2.11 (VDD), U2.28 (VDD), U2.50 (VDD), U2.73 (VDDUSB), U2.75 (VDD), U2.100 (VDD)
+5VD: C7.1, C9.1, C11.1, C17.2, C18.2, JOLED1.2, R6.1, R7.2, U3.3 (EN), U3.4 (VIN), U4.1 (VIN), U4.3 (EN); also elsewhere on the board
/Control/ADCS1: C3.2, C26.2, JP5.2, R8.1, TP10.1, U1.1, U2.24 (PA1)
/Control/ADCS2: C4.1, C27.2, JP6.2, R9.1, TP11.1, U1.7, U2.25 (PA2)
/Control/ADCSIG1: R2.2, TP2.1; also elsewhere on the board
/Control/ADCSIG2: R1.2, TP1.1; also elsewhere on the board
/Control/BTN1: R11.2, U2.57 (PD10), U_BTN1.4
/Control/BTN2: R12.2, U2.58 (PD11), U_BTN3.4
/Control/BTN3: R13.2, U2.59 (PD12), U_BTN5.4
/Control/BTN4: R10.2, U2.60 (PD13), U_BTN2.4
/Control/DACOUT1: U2.29 (PA4); also elsewhere on the board
/Control/DACOUT2: U2.30 (PA5); also elsewhere on the board
/Control/KEYPAD1: J_KEYPAD1.1, U2.38 (PE7)
/Control/KEYPAD2: J_KEYPAD1.2, U2.39 (PE8)
/Control/KEYPAD3: J_KEYPAD1.3, U2.40 (PE9)
/Control/KEYPAD4: J_KEYPAD1.4, U2.41 (PE10)
/Control/KEYPAD5: J_KEYPAD1.5, U2.35 (PB0)
/Control/KEYPAD6: J_KEYPAD1.6, U2.36 (PB1)
/Control/KEYPAD7: J_KEYPAD1.7, U2.37 (PB2)
/Control/NRST: C6.1, J_SWJ_DB1.5, R14.2, R15.2, TP24.1, U2.14 (NRST), U_BTNRST1.4
/Control/OLED_RST: JOLED1.5, U2.12 (PH0)
/Control/OLED_SCL: C24.2, JOLED1.3, R7.1, TP21.1, U2.92 (PB6)
/Control/OLED_SDA: C25.1, JOLED1.4, R6.2, TP20.1, U2.93 (PB7)
/Control/SWCLK: J_SWJ_DB1.2, TP22.1, U2.76 (PA14)
/Control/SWDIO: J_SWJ_DB1.4, TP23.1, U2.72 (PA13)
/Control/SWO: J_SWJ_DB1.6, TP25.1, U2.89 (PB3)
GNDS: C1.2, C2.1, C5.2, C6.2, C7.2, C8.2, C9.2, C10.2, C11.2, C12.2, C13.2, C14.2, C15.2, C16.2, C17.1, C18.1, C19.2, C20.2, C21.1, C22.2, C23.2, C24.1, C25.2, C28.2, C29.2, C30.2, JOLED1.1, J_SWJ_DB1.3, R5.2, TPG1.1, TPG2.1, TPG3.1, TPG4.1, TPG5.1, TPG6.1, TPG7.1, TPG8.1, TPG9.1, TPG10.1, U1.4 (V-), U2.6 (VBAT), U2.10 (VSS), U2.19 (VSSA), U2.20 (VREF-), U2.27 (VSS), U2.49 (VSS), U2.74 (VSS), U2.99 (VSS), U3.2 (GND), U4.2 (GND), U_BTN1.2, U_BTN2.2, U_BTN3.2, U_BTN5.2, U_BTNRST1.2; also elsewhere on the board
unnamed: C1.1, JP5.1, R3.1, U1.3 (+)
unnamed: C2.2, JP6.1, R4.1, U1.5 (+)
unnamed: C3.1, R2.1, R3.2
unnamed: C4.2, R1.1, R4.2
unnamed: C21.2, L1.1, TP18.1, U3.5 (VREF)
unnamed: C22.1, L2.1, TP19.1, U4.5 (VOUT)
unnamed: C26.1, R8.2, U1.2 (-)
unnamed: C27.1, R9.2, U1.6 (-)
unnamed: R5.1, U2.94 (PH3)

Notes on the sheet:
Micro Controller
Input Section
Output Section
GPIO_EXTI0 (PDWN)
GPIO_EXTI1 (PDWN)
GPIO_EXTI2 (PDWN)
GPIO_OUTPUT (PDWN)
EXTI (PUP)
To be used with: Front-mounted keypad, non-shielded, non-backlit. Grayhill-96AB2-102-F http://www.grayhill.com/assets/1/7/Keypads_96.pdf
8-position connector with 1 position removed.
Voltage Regulator and Voltage Reference
TO BYPASS: 1) Remove U1 2) Solder JP5, JP6, R1 and R2 3) Populate R3, R4 with 100R and C1, C2 with 100nF for FC=15KHz
Passives footprint to be left empty if direct PCB connection is used.
OLED_RST (PUP)

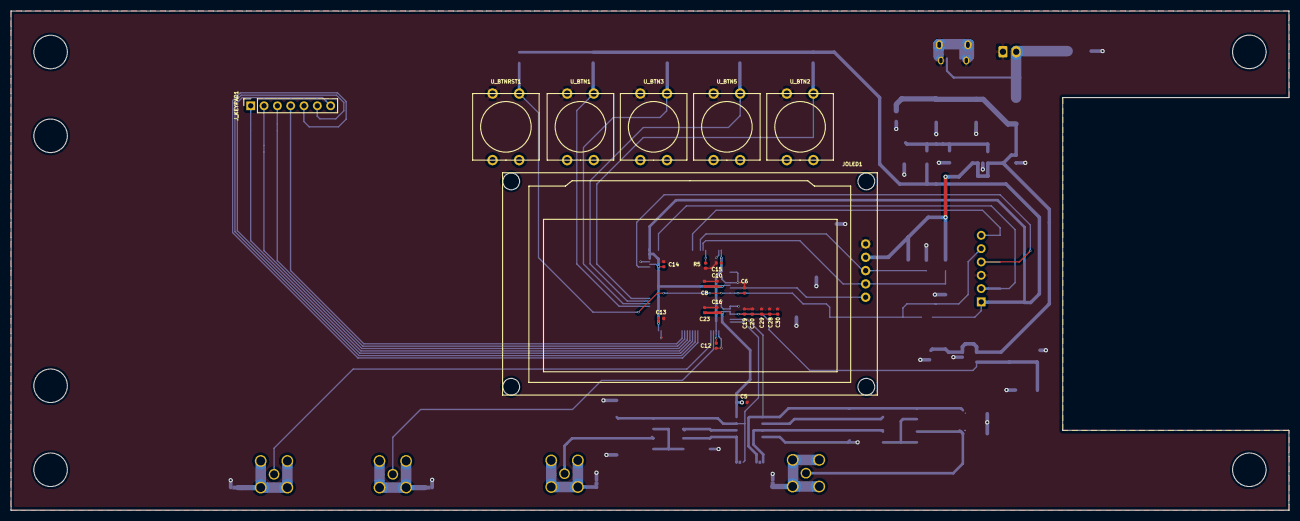
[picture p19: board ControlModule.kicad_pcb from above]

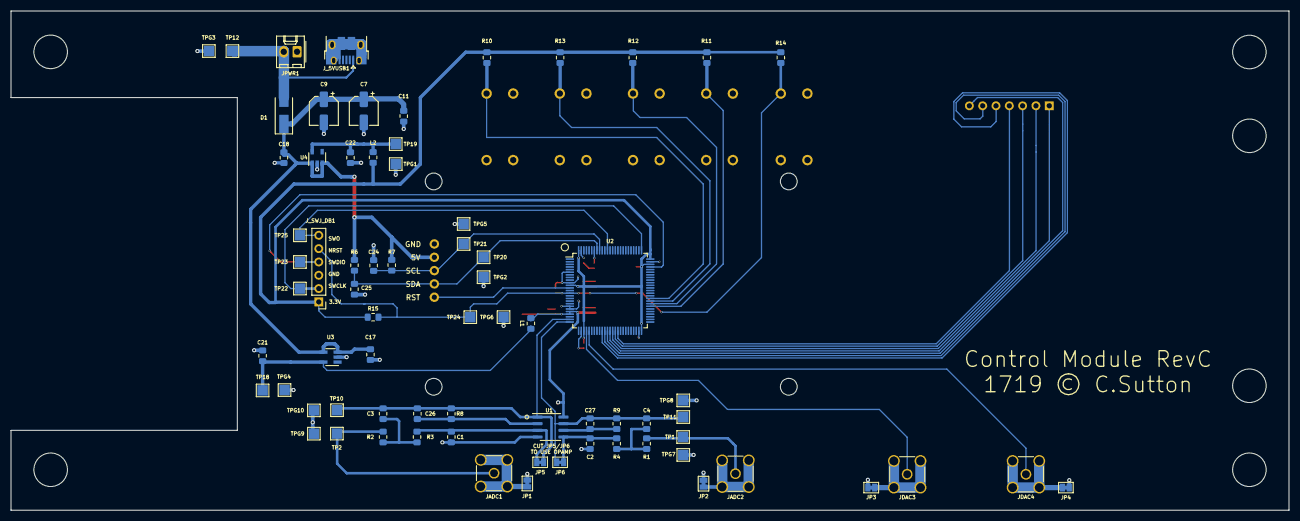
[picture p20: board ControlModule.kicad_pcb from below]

Board: 2 copper layers, 243.8 x 95.2 mm, 95 parts (72 on the bottom side), 42 nets.

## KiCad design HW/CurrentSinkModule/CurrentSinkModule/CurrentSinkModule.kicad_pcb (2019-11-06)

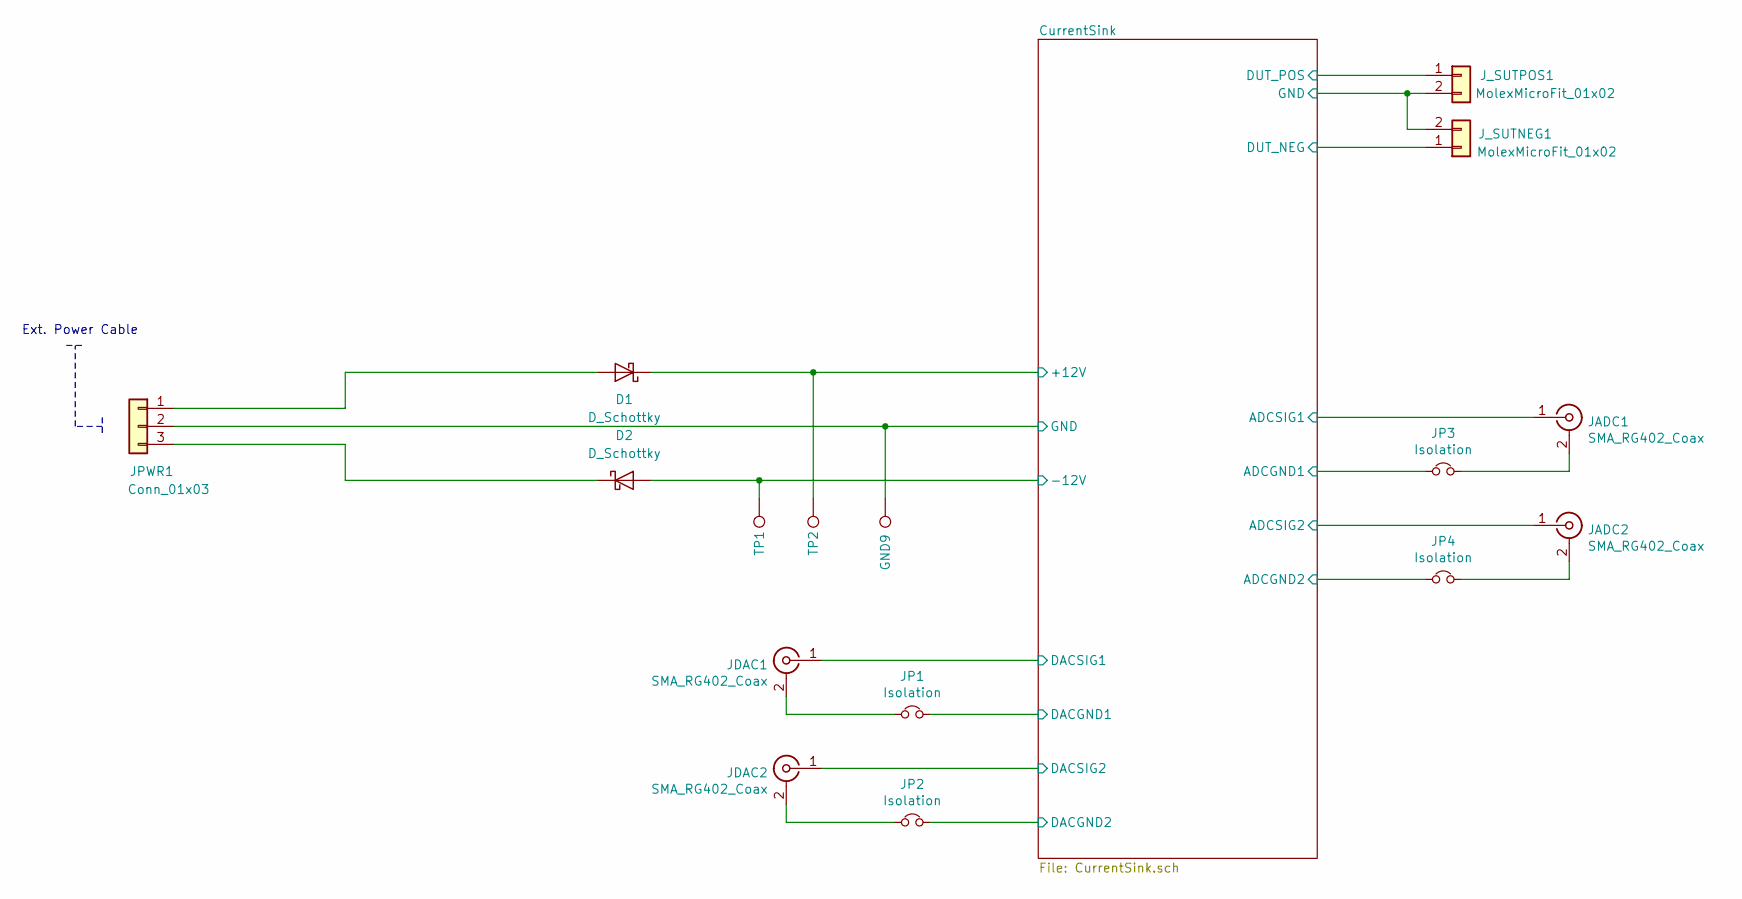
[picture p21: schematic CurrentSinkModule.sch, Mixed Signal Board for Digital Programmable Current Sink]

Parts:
D1, D2: D_Schottky; D_SOD-123
GND9: TestPoint; TestPoint_Pad_2.0x2.0mm; MouserNo 855-S2751-46R
JADC1, JADC2: SMA_RG402_Coax; SMA_Amphenol_901-144_Vertical; DigikeyNo A97594-ND
JDAC1, JDAC2: SMA_RG402_Coax; SMA_Amphenol_901-144_Vertical; DigikeyNo A97594-ND
JP1, JP2, JP3, JP4: Isolation; SolderJumper-2_P1.3mm_Open_Pad1.0x1.5mm
JPWR1: Conn_01x03; Molex_KK-254_AE-6410-03A_1x03_P2.54mm_Vertical
J_SUTNEG1: MolexMicroFit_01x02; Molex_Micro-Fit_3.0_43045-0212_2x01_P3.00mm_Vertical
J_SUTPOS1: MolexMicroFit_01x02; Molex_Micro-Fit_3.0_43045-0212_2x01_P3.00mm_Vertical
TP1, TP2: TestPoint; TestPoint_Pad_2.0x2.0mm; MouserNo 855-S2751-46R

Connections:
+12V: D1.1 (K), TP2.1; also elsewhere on the board
-12V: D2.2 (A), TP1.1; also elsewhere on the board
/CurrentSink/ADCSIG1: JADC1.1 (In); also elsewhere on the board
/CurrentSink/ADCSIG2: JADC2.1 (In); also elsewhere on the board
/CurrentSink/DACSIG1: JDAC1.1 (In); also elsewhere on the board
/CurrentSink/DACSIG2: JDAC2.1 (In); also elsewhere on the board
/CurrentSink/DUT_NEG: J_SUTNEG1.1; also elsewhere on the board
/CurrentSink/DUT_POS: J_SUTPOS1.1; also elsewhere on the board
GNDS: GND9.1, JP1.2, JP2.2, JP3.1, JP4.1, JPWR1.2, J_SUTNEG1.2, J_SUTPOS1.2; also elsewhere on the board
unnamed: D1.2 (A), JPWR1.1
unnamed: D2.1 (K), JPWR1.3
unnamed: JADC1.2 (Ext), JP3.2
unnamed: JADC2.2 (Ext), JP4.2
unnamed: JDAC1.2 (Ext), JP1.1
unnamed: JDAC2.2 (Ext), JP2.1

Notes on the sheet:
Ext. Power Cable

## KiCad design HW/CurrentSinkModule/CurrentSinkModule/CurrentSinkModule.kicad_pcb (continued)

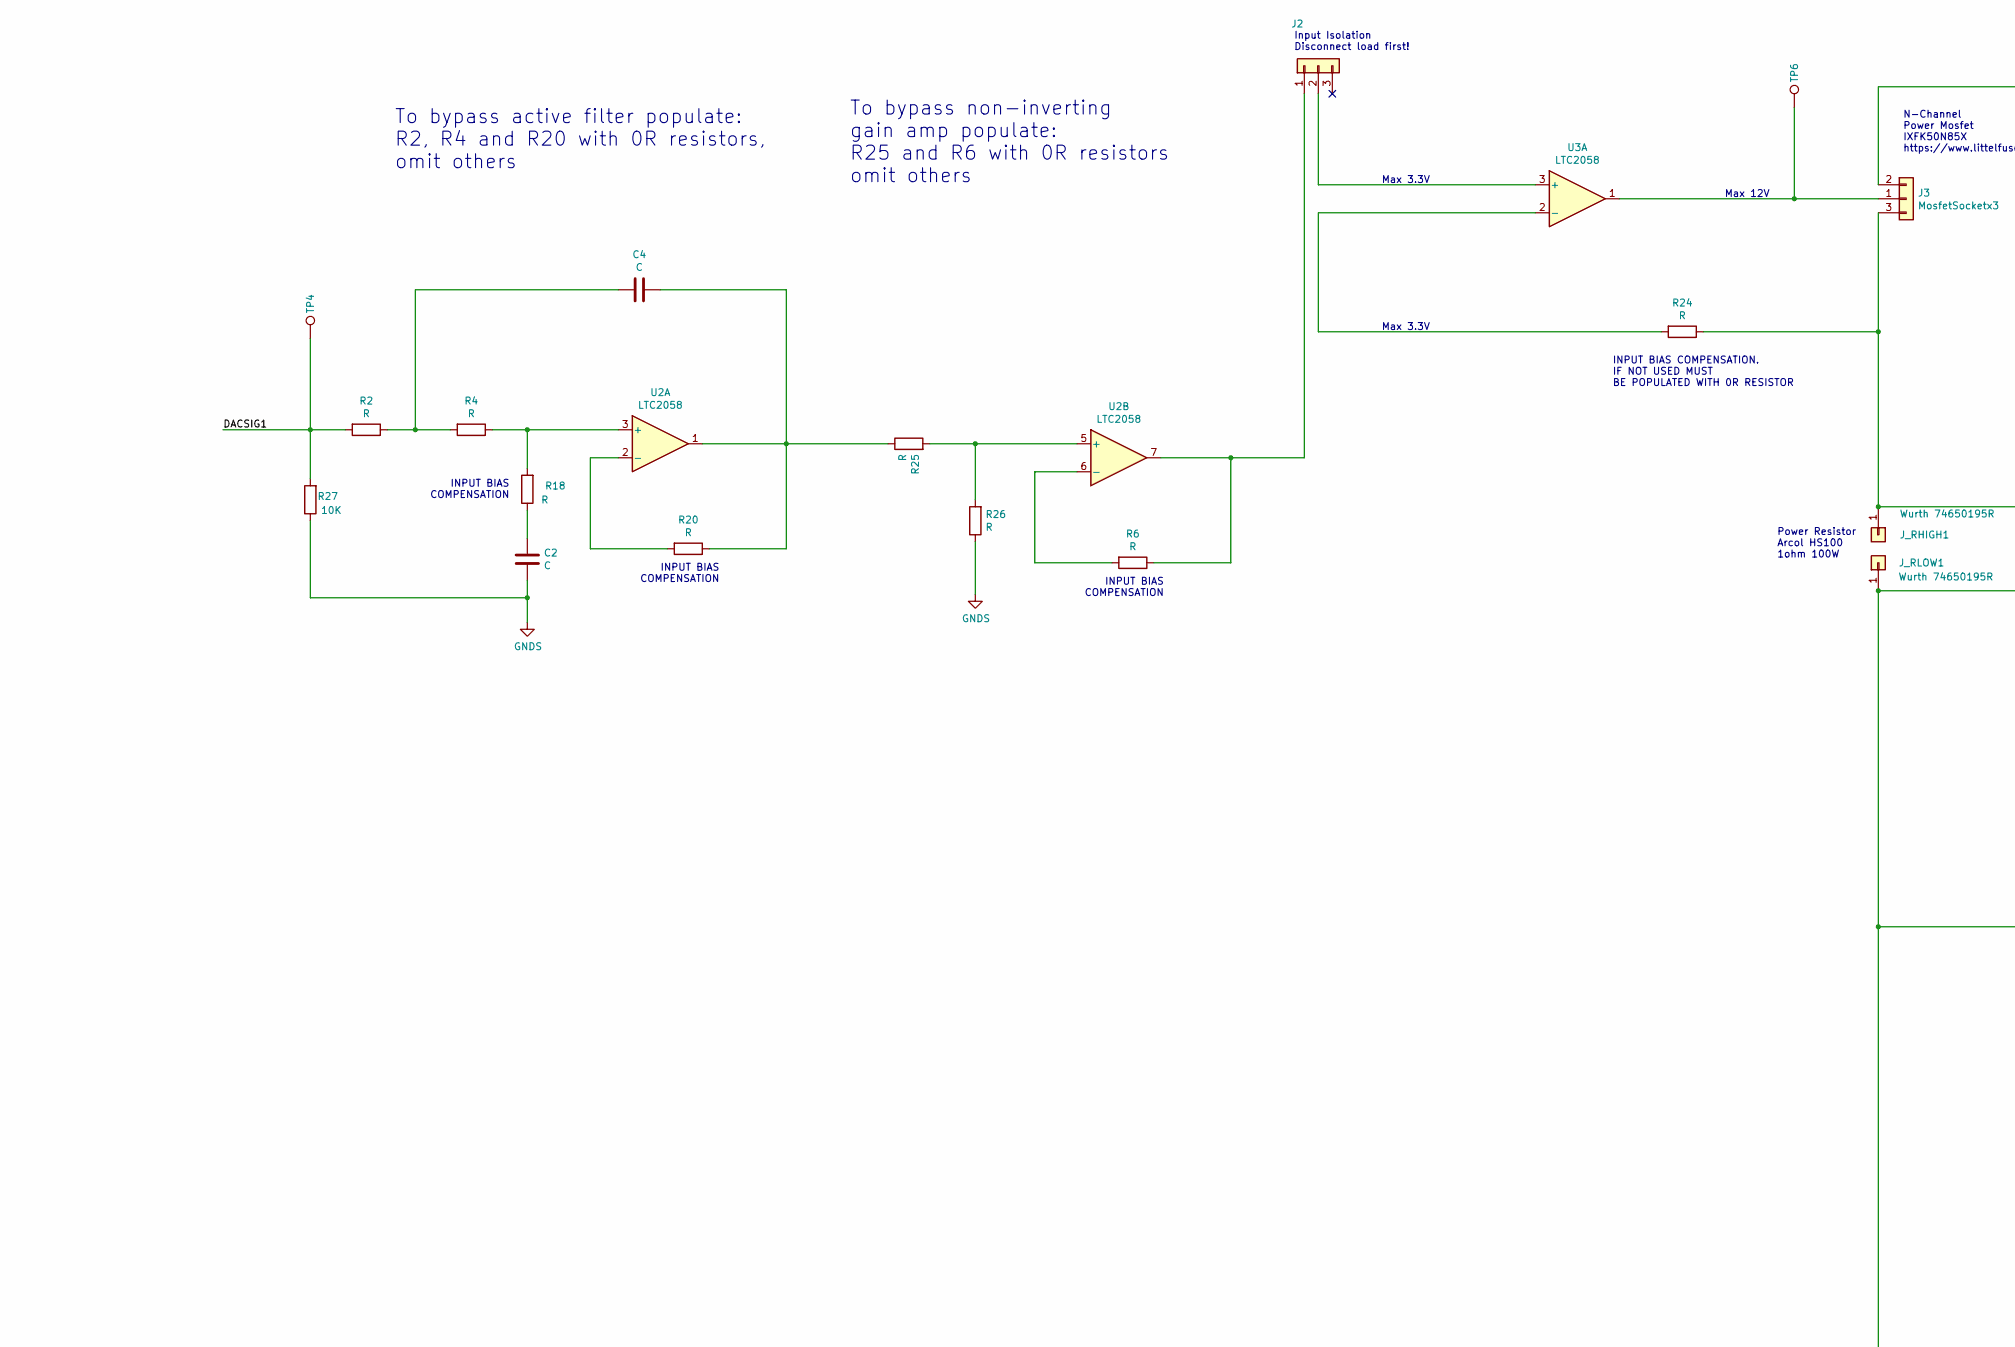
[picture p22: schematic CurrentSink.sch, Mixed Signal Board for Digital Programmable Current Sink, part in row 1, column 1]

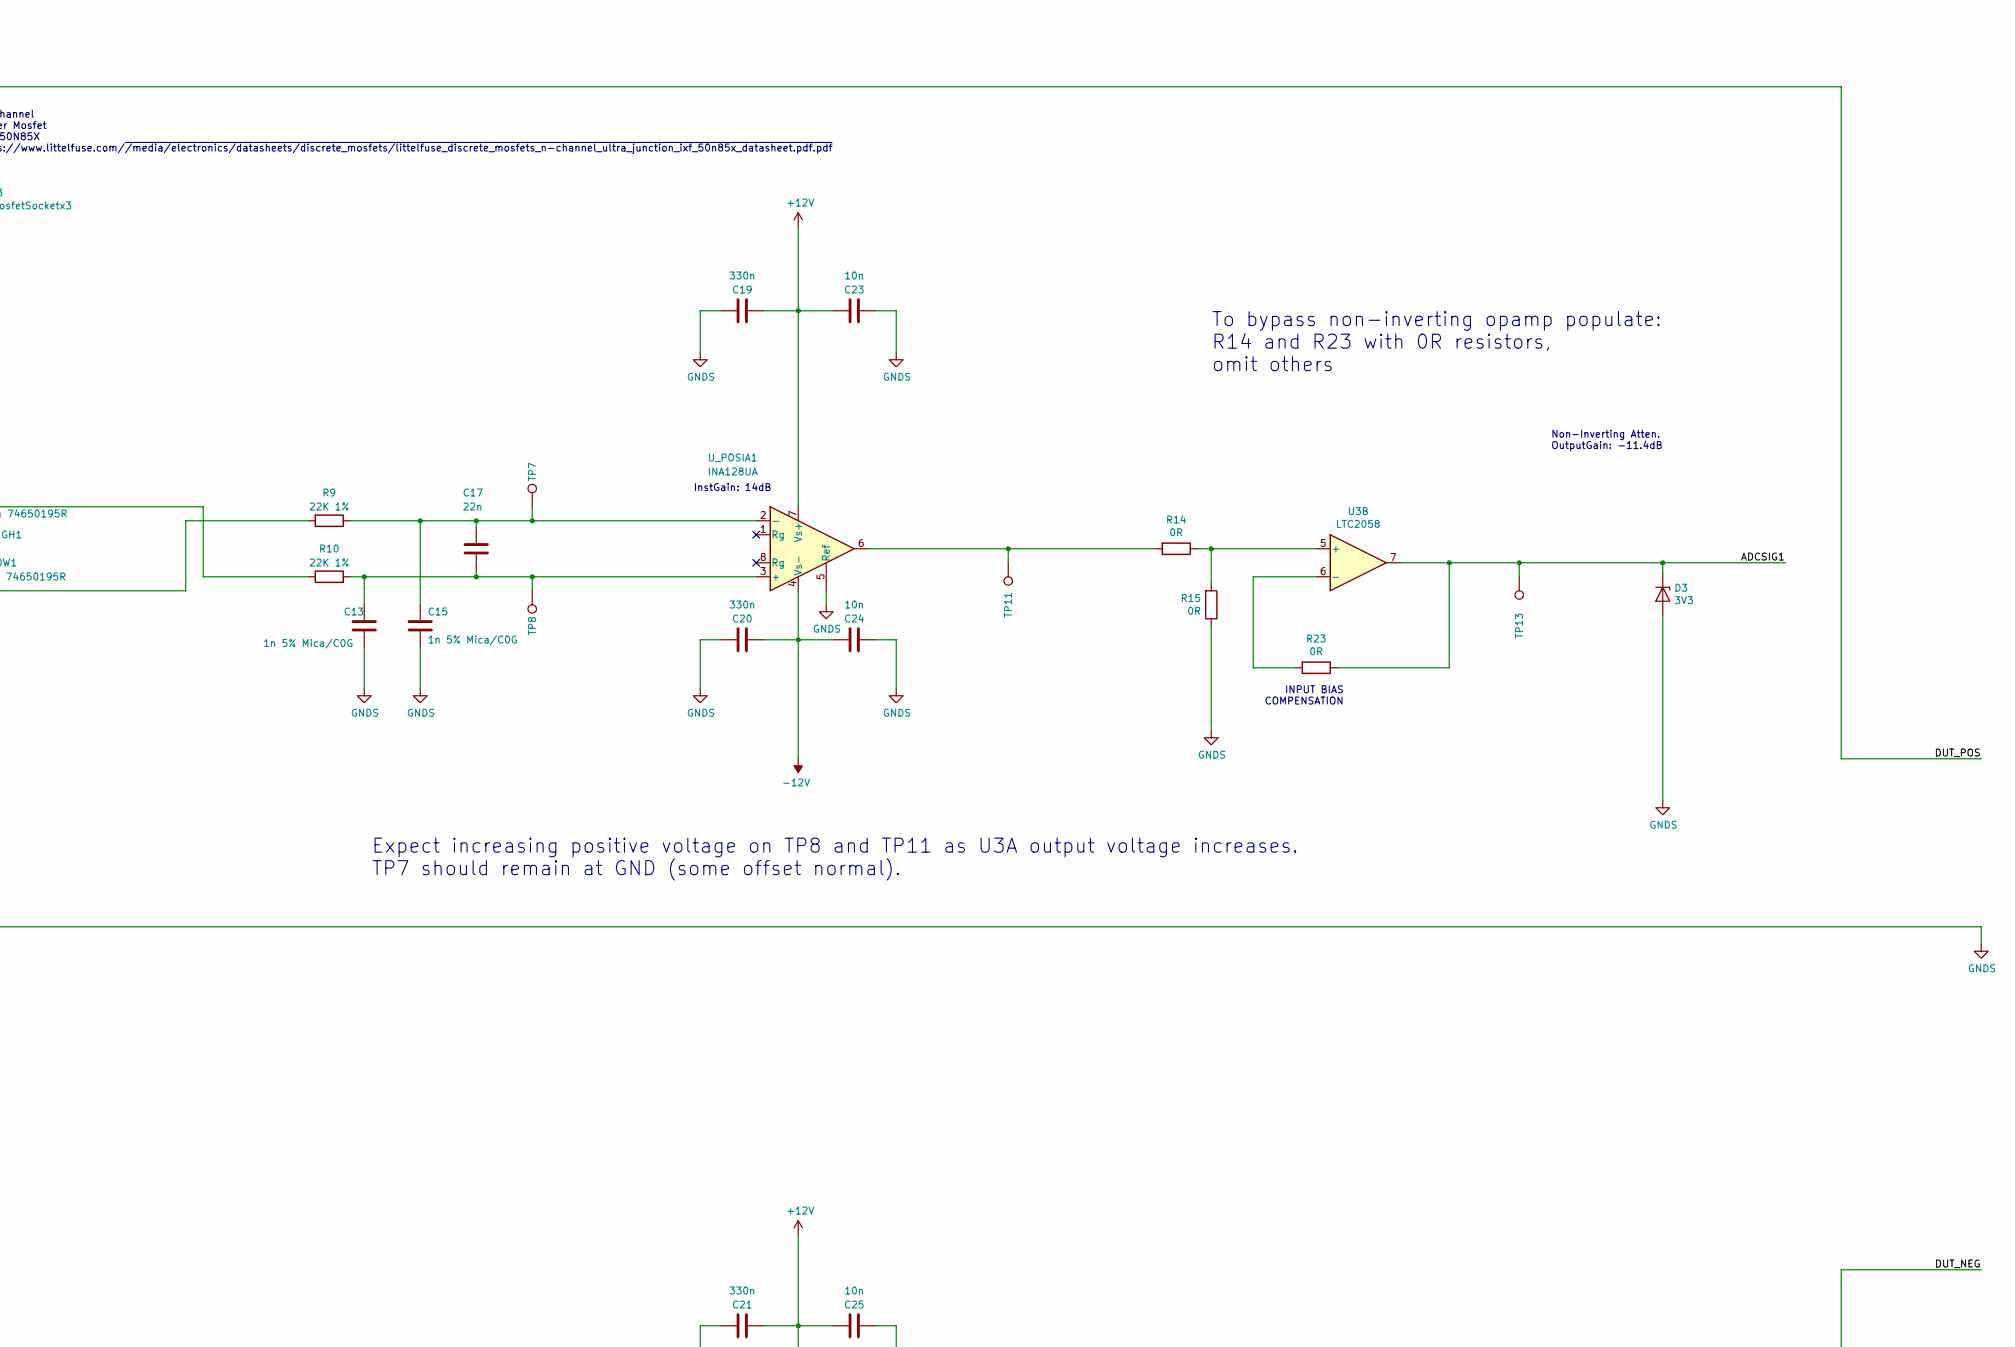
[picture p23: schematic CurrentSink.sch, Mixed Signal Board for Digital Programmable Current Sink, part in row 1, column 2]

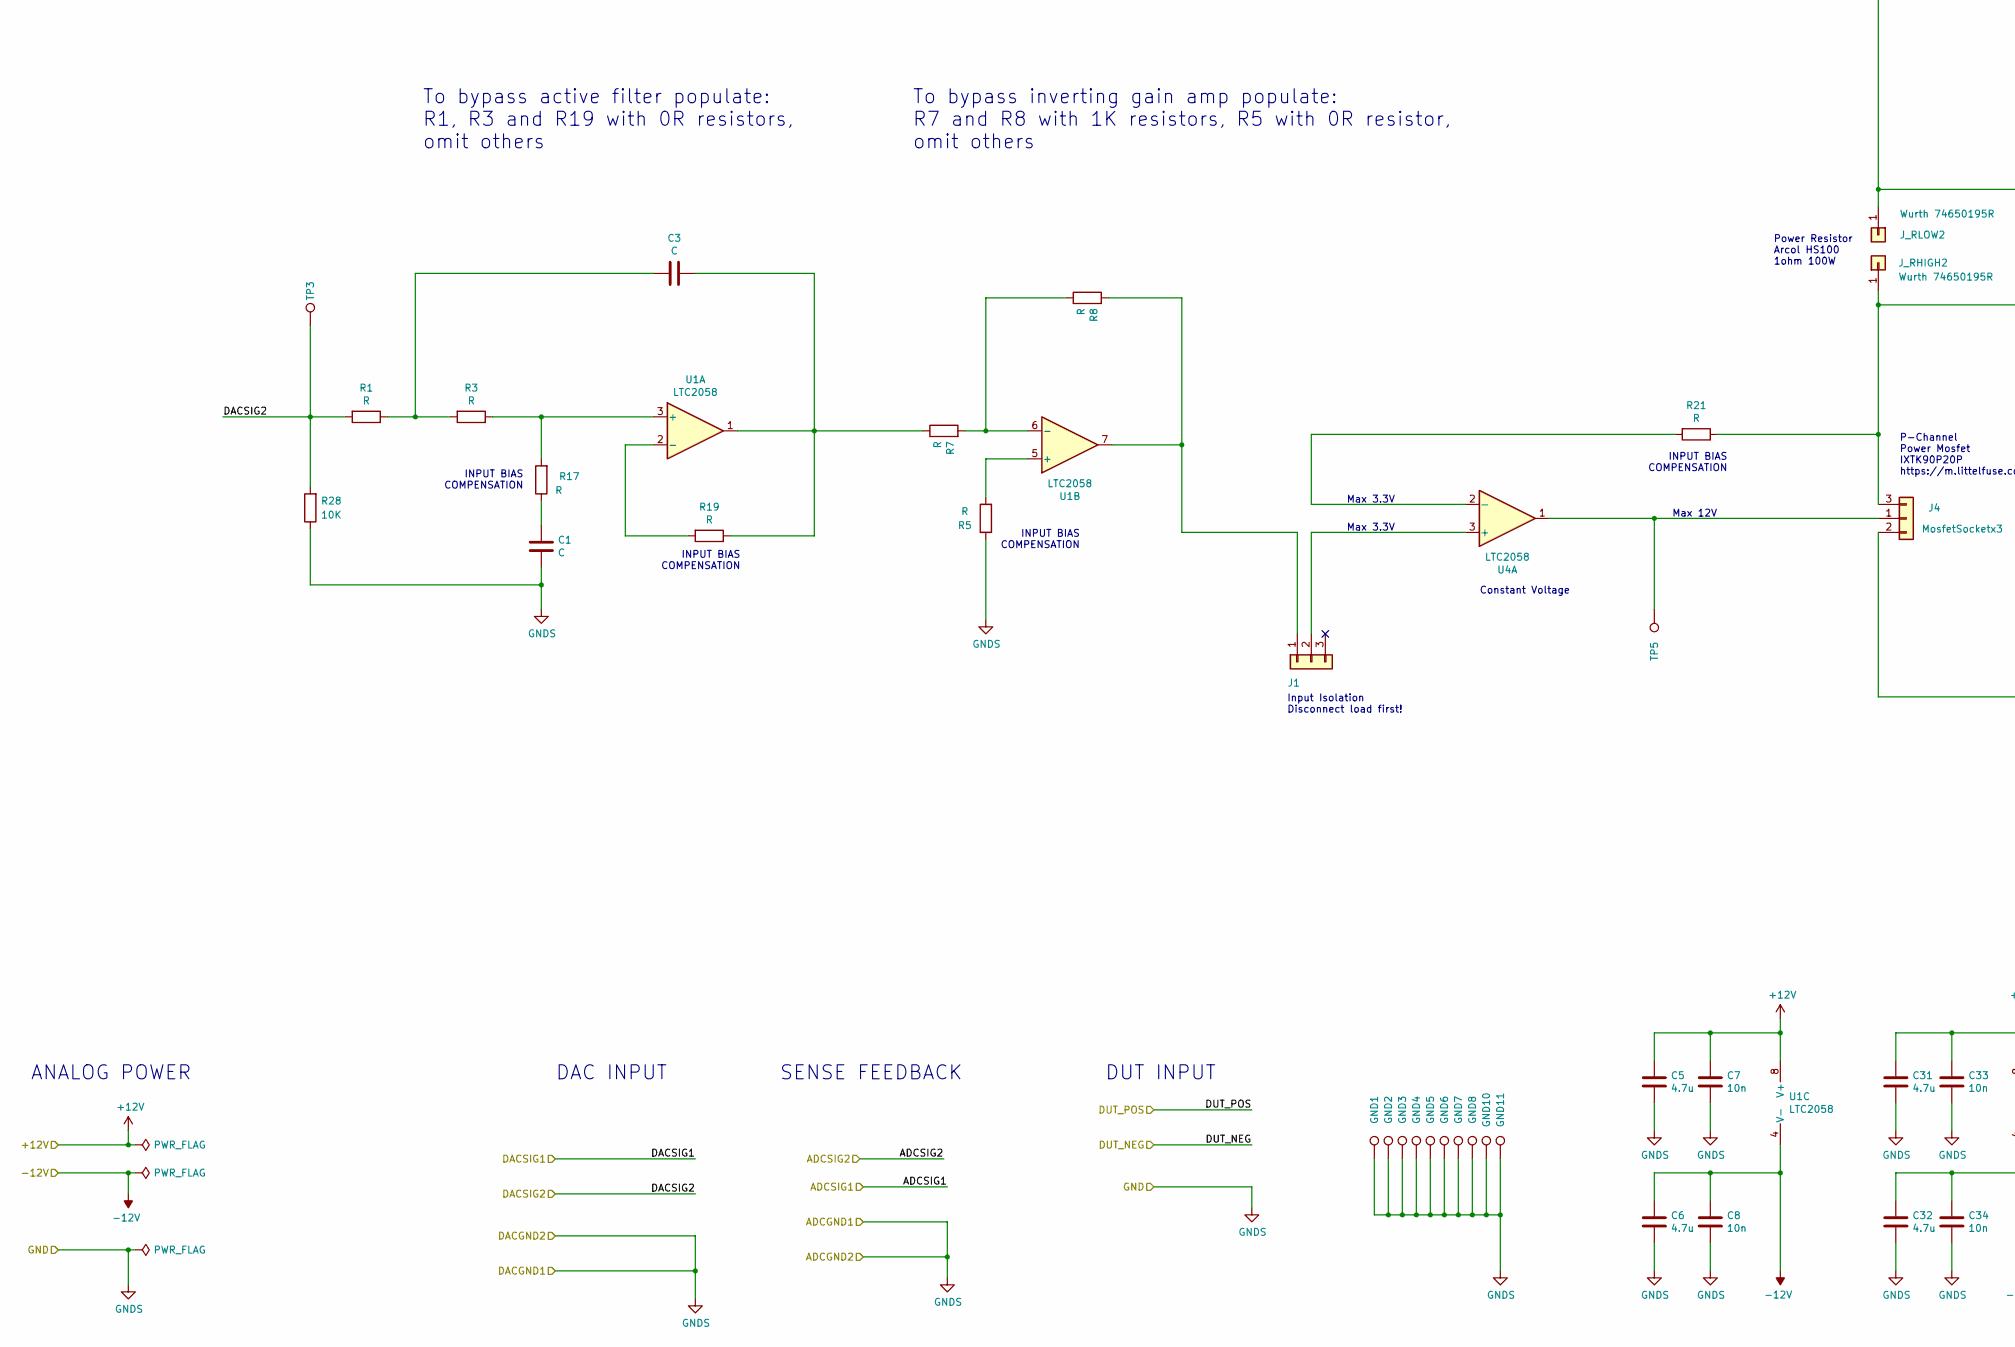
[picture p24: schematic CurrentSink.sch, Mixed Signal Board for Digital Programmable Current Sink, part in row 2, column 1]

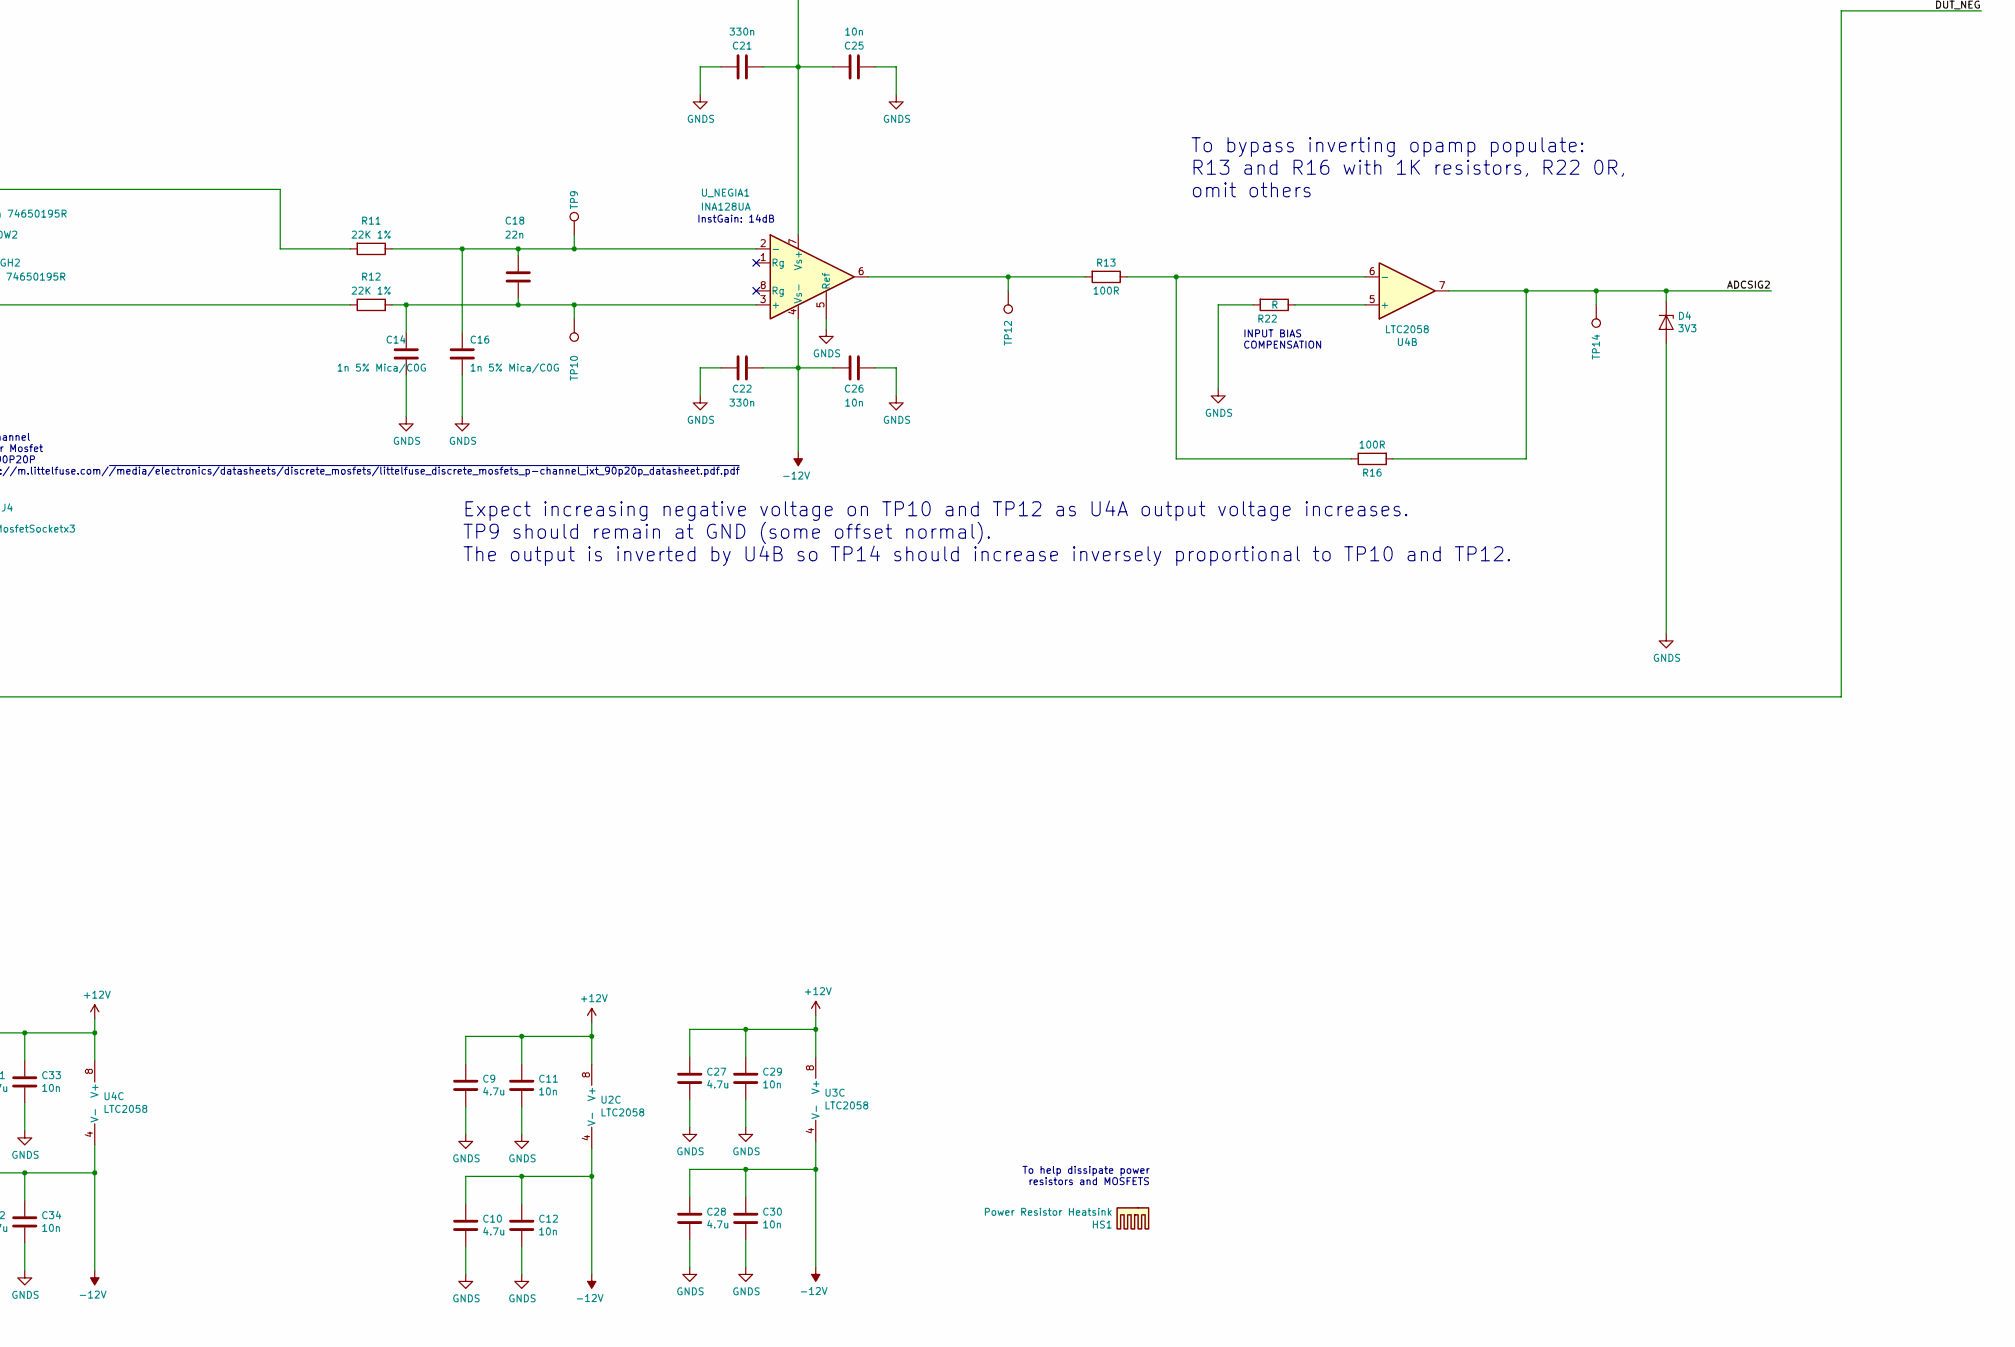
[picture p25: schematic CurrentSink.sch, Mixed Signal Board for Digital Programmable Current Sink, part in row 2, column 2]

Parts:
C1, C2, C3, C4: C; C_0402_1005Metric
C5, C6, C9, C10, C27, C28, C31, C32: 4.7u; C_0402_1005Metric
C7, C8, C11, C12, C23, C24, C25, C26, C29, C30, C33, C34: 10n; C_0402_1005Metric
C13, C14, C15, C16: 1n 5% Mica/C0G; C_0402_1005Metric
C17, C18: 22n; C_0402_1005Metric
C19, C20, C21, C22: 330n; C_0402_1005Metric
D3, D4: 3V3; D_SOD-123
GND1, GND2, GND3, GND4, GND5, GND6, GND7, GND8, GND10, GND11: TestPoint; TestPoint_Pad_2.0x2.0mm; MouserNo 855-S2751-46R
HS1: Power Resistor Heatsink; LAM_5_100_12; MouserNo 774-2811
J1, J2: Conn_01x03; PinHeader_1x03_P2.54mm_Vertical
J3, J4: MosfetSocketx3; TerminalBlock_bornier-3_P5.08mm
J_RHIGH1, J_RHIGH2: Wurth 74650195R; Wurth_74651173
J_RLOW1, J_RLOW2: Wurth 74650195R; Wurth_74651173
R1, R2, R3, R4, R5, R6, R7, R8, R17, R18, R19, R20, R22, R25, R26: R; R_0402_1005Metric
R9, R10, R11, R12: 22K 1%; R_0402_1005Metric
R13, R16: 100R; R_0402_1005Metric
R14, R15, R23: 0R; R_0402_1005Metric
R21, R24: R; R_0805_2012Metric_Pad1.15x1.40mm_HandSolder
R27, R28: 10K; R_0402_1005Metric
TP3, TP4, TP5, TP6, TP7, TP8, TP9, TP10, TP11, TP12, TP13, TP14: TestPoint; TestPoint_Pad_2.0x2.0mm; MouserNo 855-S2751-46R
U1, U2, U3, U4: LTC2058; SOIC-8_3.9x4.9mm_P1.27mm; MouserNo 584-ADA4522-2ARMZ
U_NEGIA1: INA128UA; SOIC-8_3.9x4.9mm_P1.27mm; MouserNo 595-INA128UA/2K5
U_POSIA1: INA128UA; SOIC-8_3.9x4.9mm_P1.27mm; MouserNo 595-INA128UA/2K5

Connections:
+12V: C5.1, C7.1, C9.1, C11.1, C19.2, C21.2, C23.1, C25.1, C27.1, C29.1, C31.1, C33.1, U1.8 (V+), U2.8 (V+), U3.8 (V+), U4.8 (V+), U_NEGIA1.7 (Vs+), U_POSIA1.7 (Vs+); also elsewhere on the board
-12V: C6.1, C8.1, C10.1, C12.1, C20.2, C22.2, C24.1, C26.1, C28.1, C30.1, C32.1, C34.1, U1.4 (V-), U2.4 (V-), U3.4 (V-), U4.4 (V-), U_NEGIA1.4 (Vs-), U_POSIA1.4 (Vs-); also elsewhere on the board
/CurrentSink/ADCSIG1: D3.1 (K), R23.1, TP13.1, U3.7; also elsewhere on the board
/CurrentSink/ADCSIG2: D4.1 (K), R16.2, TP14.1, U4.7; also elsewhere on the board
/CurrentSink/DACSIG1: R2.2, R27.2, TP4.1; also elsewhere on the board
/CurrentSink/DACSIG2: R1.2, R28.2, TP3.1; also elsewhere on the board
/CurrentSink/DUT_NEG: J4.2; also elsewhere on the board
/CurrentSink/DUT_POS: J3.2; also elsewhere on the board
GNDS: C1.2, C2.2, C5.2, C6.2, C7.2, C8.2, C9.2, C10.2, C11.2, C12.2, C13.2, C14.2, C15.2, C16.2, C19.1, C20.1, C21.1, C22.1, C23.2, C24.2, C25.2, C26.2, C27.2, C28.2, C29.2, C30.2, C31.2, C32.2, C33.2, C34.2, D3.2 (A), D4.2 (A), GND1.1, GND2.1, GND3.1, GND4.1, GND5.1, GND6.1, GND7.1, GND8.1, GND10.1, GND11.1, J_RLOW1.1, J_RLOW2.1, R5.1, R9.2, R11.2, R15.1, R22.2, R26.1, R27.1, R28.1, U_NEGIA1.5 (Ref), U_POSIA1.5 (Ref); also elsewhere on the board
unnamed: C1.1, R17.1
unnamed: C2.1, R18.1
unnamed 11: C3.1, R7.1, R19.1, U1.1; also elsewhere on the board
unnamed: C3.2, R1.1, R3.2
unnamed 13: C4.1, R20.1, R25.1, U2.1; also elsewhere on the board
unnamed: C4.2, R2.1, R4.2
unnamed: C13.1, C17.2, R10.2, TP8.1, U_POSIA1.3 (+)
unnamed: C14.1, C18.2, R12.2, TP10.1, U_NEGIA1.3 (+)
unnamed: C15.1, C17.1, R9.1, TP7.1, U_POSIA1.2 (-)
unnamed: C16.1, C18.1, R11.1, TP9.1, U_NEGIA1.2 (-)
unnamed 21: J1.1, R8.2, U1.7; also elsewhere on the board
unnamed: J1.2, U4.3 (+)
unnamed 23: J2.1, R6.1, U2.7; also elsewhere on the board
unnamed: J2.2, U3.3 (+)
unnamed: J3.1, TP6.1, U3.1
unnamed: J3.3, J_RHIGH1.1, R10.1, R24.1
unnamed: J4.1, TP5.1, U4.1
unnamed: J4.3, J_RHIGH2.1, R12.1, R21.1
unnamed 33: R3.1, R17.2, U1.3 (+); also elsewhere on the board
unnamed 34: R4.1, R18.2, U2.3 (+); also elsewhere on the board
unnamed 35: R7.2, R8.1, U1.6 (-); also elsewhere on the board
unnamed 36: R6.2, U2.6 (-); also elsewhere on the board
unnamed 37: R13.2, TP12.1, U_NEGIA1.6; also elsewhere on the board
unnamed 38: R14.2, TP11.1, U_POSIA1.6; also elsewhere on the board
unnamed: R5.2, U1.5 (+)
unnamed: R13.1, R16.1, U4.6 (-)
unnamed: R14.1, R15.2, U3.5 (+)
unnamed: R19.2, U1.2 (-)
unnamed: R20.2, U2.2 (-)
unnamed: R21.2, U4.2 (-)
unnamed: R22.1, U4.5 (+)
unnamed: R23.2, U3.6 (-)
unnamed: R24.2, U3.2 (-)
unnamed: R25.2, R26.2, U2.5 (+)

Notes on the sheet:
To help dissipate power resistors and MOSFETS
ANALOG POWER
DAC INPUT
SENSE FEEDBACK
DUT INPUT
N-Channel Power Mosfet IXFK50N85X https://www.littelfuse.com/~/media/electronics/datasheets/discrete_mosfets/littelfuse_discrete_mosfets_n-channel_ultra_junction_ixf_50n85x_datasheet.pdf.pdf
Power Resistor Arcol HS100 1ohm 100W
P-Channel Power Mosfet IXTK90P20P https://m.littelfuse.com/~/media/electronics/datasheets/discrete_mosfets/littelfuse_discrete_mosfets_p-channel_ixt_90p20p_datasheet.pdf.pdf
InstGain: 14dB
Non-Inverting Atten. OutputGain: -11.4dB
Input Isolation Disconnect load first!
Constant Voltage
INPUT BIAS COMPENSATION
INPUT BIAS COMPENSATION. IF NOT USED MUST BE POPULATED WITH 0R RESISTOR
Max 3.3V
Max 12V
To bypass active filter populate: R2, R4 and R20 with 0R resistors, omit others
To bypass active filter populate: R1, R3 and R19 with 0R resistors, omit others
To bypass inverting gain amp populate: R7 and R8 with 1K resistors, R5 with 0R resistor, omit others
To bypass non-inverting gain amp populate: R25 and R6 with 0R resistors omit others
To bypass non-inverting opamp populate: R14 and R23 with 0R resistors, omit others
To bypass inverting opamp populate: R13 and R16 with 1K resistors, R22 0R, omit others
Expect increasing negative voltage on TP10 and TP12 as U4A output voltage increases. TP9 should remain at GND (some offset normal). The output is inverted by U4B so TP14 should increase inversely proportional to TP10 and TP12.
Expect increasing positive voltage on TP8 and TP11 as U3A output voltage increases. TP7 should remain at GND (some offset normal).

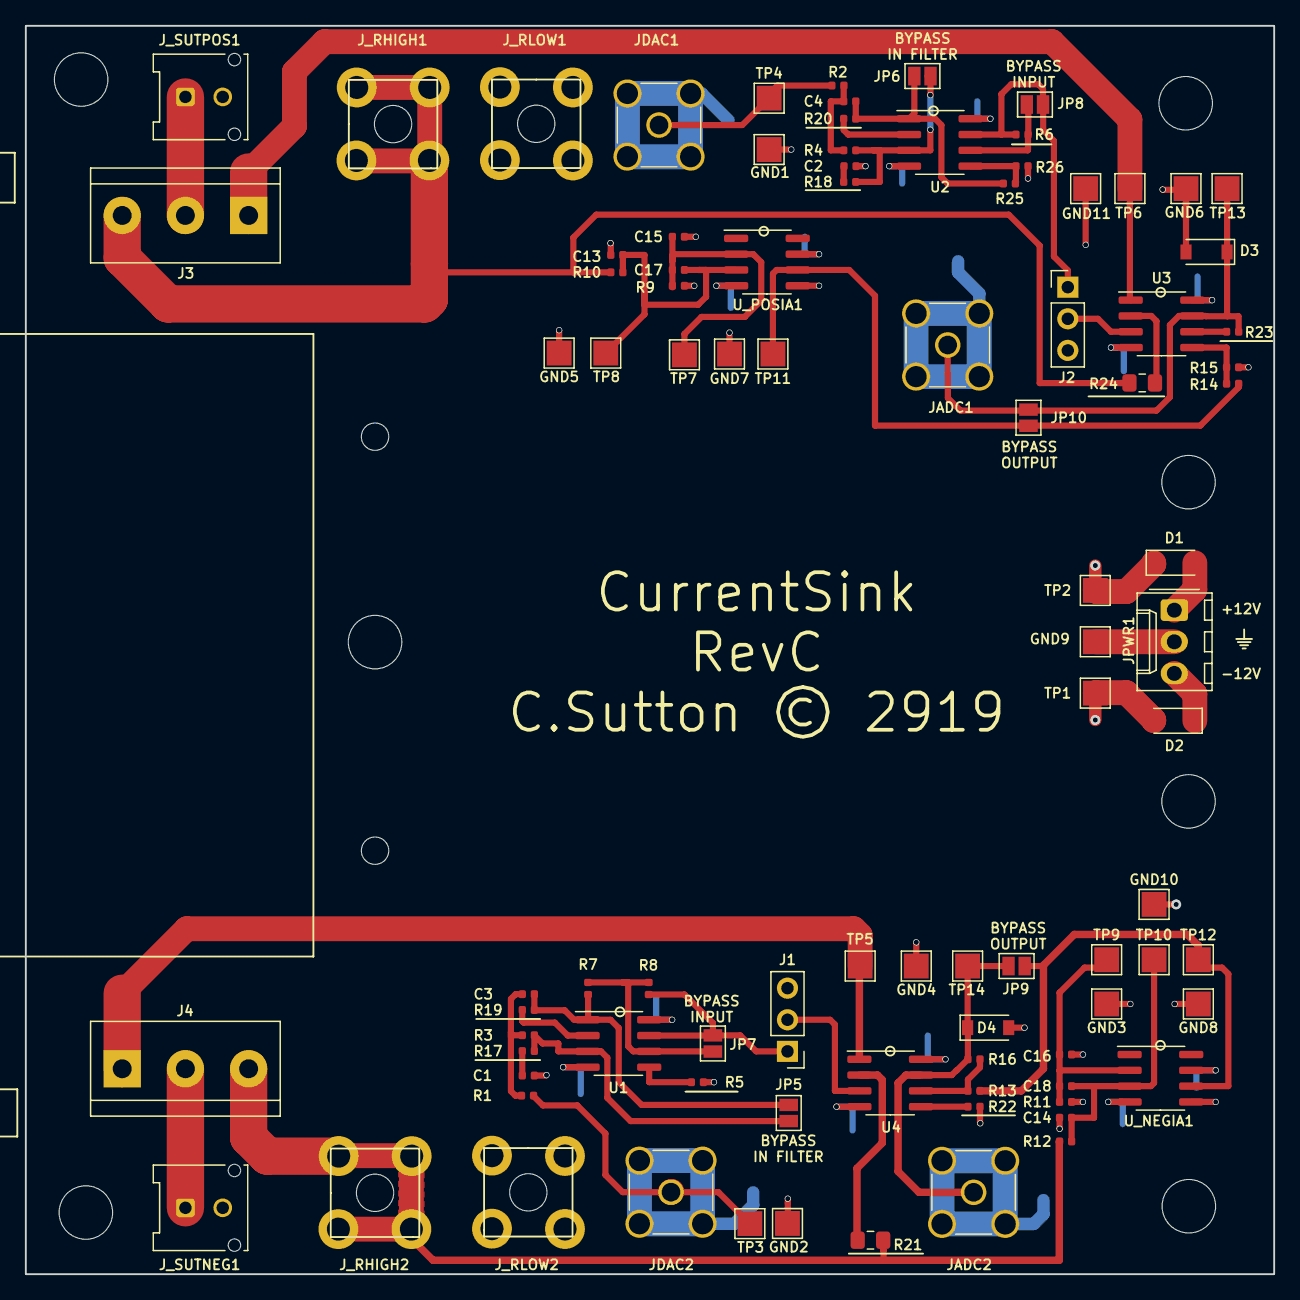
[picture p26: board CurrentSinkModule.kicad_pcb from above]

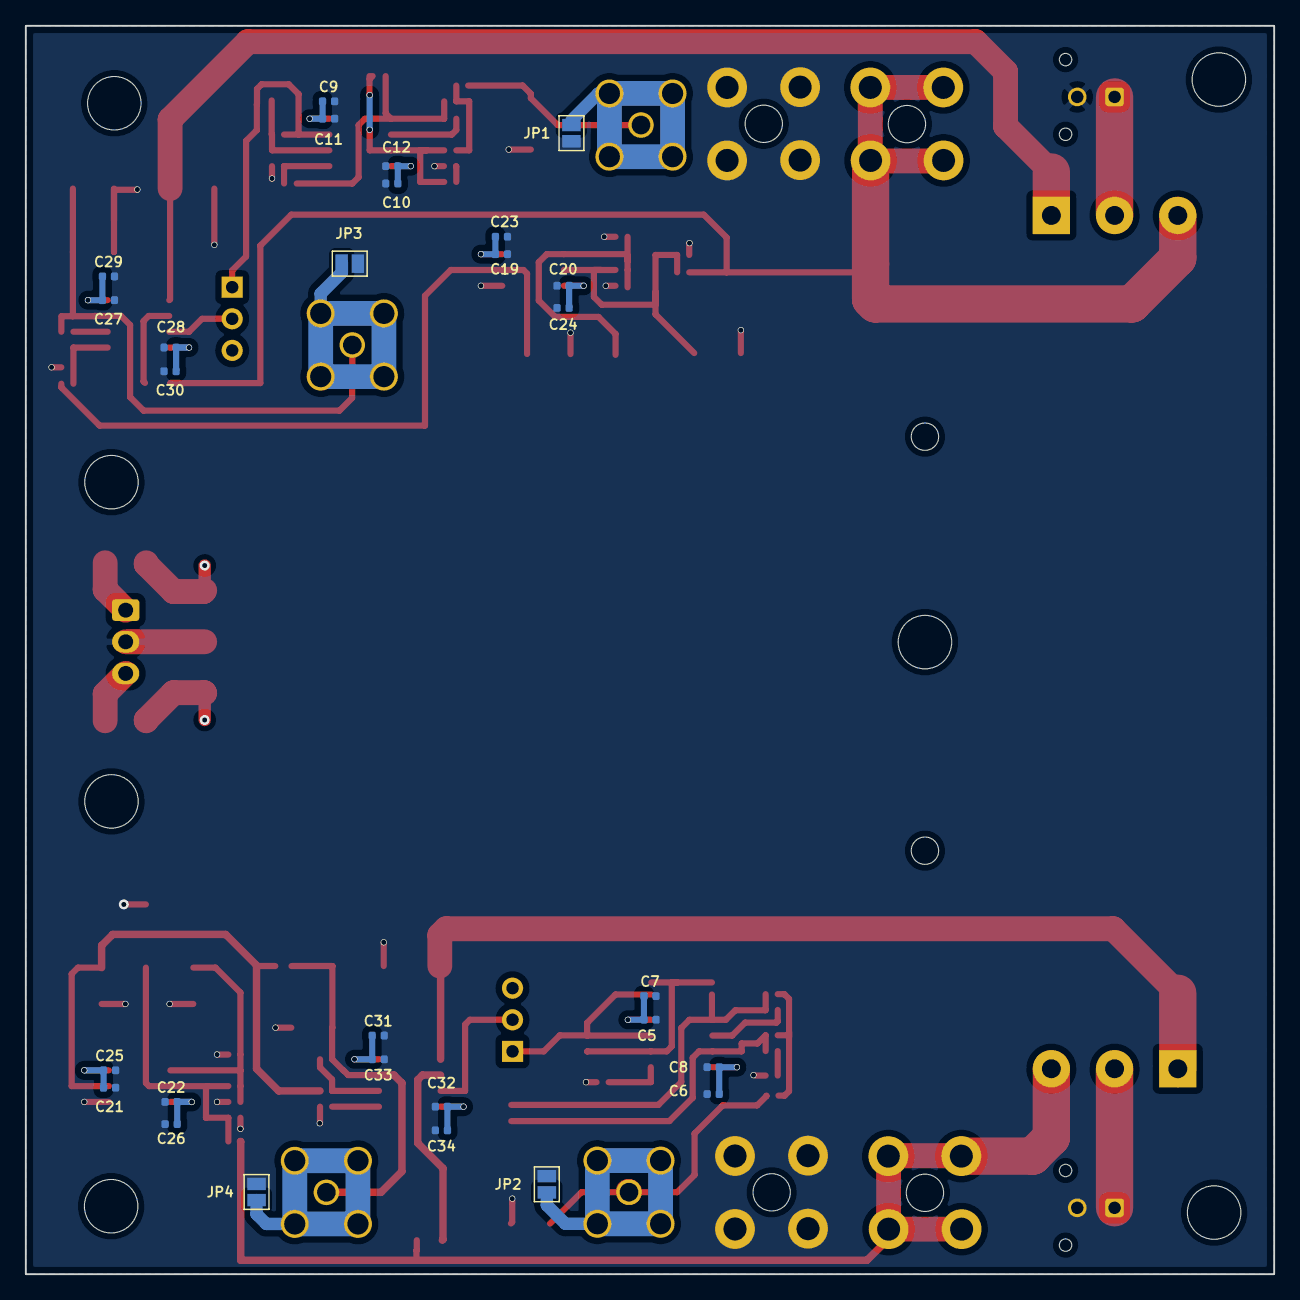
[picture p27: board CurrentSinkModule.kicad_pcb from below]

Board: 4 copper layers, 100.3 x 100.3 mm, 121 parts (28 on the bottom side), 49 nets.

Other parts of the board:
JP5, JP6, JP7, JP8, JP9, JP10: BYPASS; SolderJumper-2_P1.3mm_Open_Pad1.0x1.5mm

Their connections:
/CurrentSink/ADCSIG1: JP10.2; also elsewhere on the board
/CurrentSink/ADCSIG2: JP9.2; also elsewhere on the board
unnamed 11: JP5.2; also elsewhere on the board
unnamed 13: JP6.2; also elsewhere on the board
unnamed 21: JP7.2; also elsewhere on the board
unnamed 23: JP8.2; also elsewhere on the board
unnamed 33: JP5.1; also elsewhere on the board
unnamed 34: JP6.1; also elsewhere on the board
unnamed 35: JP7.1; also elsewhere on the board
unnamed 36: JP8.1; also elsewhere on the board
unnamed 37: JP9.1; also elsewhere on the board
unnamed 38: JP10.1; also elsewhere on the board

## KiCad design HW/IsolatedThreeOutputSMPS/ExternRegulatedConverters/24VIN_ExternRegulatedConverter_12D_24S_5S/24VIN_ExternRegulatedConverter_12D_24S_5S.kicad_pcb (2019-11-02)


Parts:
C1: 4.7uF; CP_Elec_4x5.7
C2, C5: 330nF; C_1206_3216Metric_Pad1.42x1.75mm_HandSolder
C3: 33p; C_1206_3216Metric_Pad1.42x1.75mm_HandSolder
C4: 220p; C_1206_3216Metric_Pad1.42x1.75mm_HandSolder
C6: 220nF; C_1206_3216Metric_Pad1.42x1.75mm_HandSolder
C7, C8, C10: 100nF; C_1206_3216Metric_Pad1.42x1.75mm_HandSolder
D1: BZT52C5V1; D_SMA_Handsoldering
D3, D4, D5, D6, D7: LED; LED_D3.0mm
J1: 24VDC; Molex_KK-254_AE-6410-02A_1x02_P2.54mm_Vertical
J2: Conn_01x07; Molex_KK-254_AE-6410-07A_1x07_P2.54mm_Vertical
Q1: IPP80P03P4L04AKSA1; TO-220-3_Vertical
R1: 100K; R_1206_3216Metric_Pad1.42x1.75mm_HandSolder
R3: 10K; R_1206_3216Metric_Pad1.42x1.75mm_HandSolder
R4: 6K8; R_1206_3216Metric_Pad1.42x1.75mm_HandSolder
R5, R6: 4K7; R_1206_3216Metric_Pad1.42x1.75mm_HandSolder
R7: 1K2; R_1206_3216Metric_Pad1.42x1.75mm_HandSolder
U1: L78L12_TO92; TO-92_Inline_Wide
U2: L79L12_TO92; TO-92_Inline_Wide
U4: R2D-2415; R2D
U5: LM7805_TO220; TO-220-3_Vertical

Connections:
+5V: C10.1, J2.6, R7.1, U5.3 (VO)
+12V: C7.1, J2.1, R5.1, U1.1 (VO)
+24V: C1.1, C3.2, C6.1, D1.1 (K), J2.4, Q1.3 (S), R3.1, R4.1, U4.2 (+Vin), U5.1 (VI)
-12V: C8.2, J2.3, R6.1, U2.3 (VO)
/+15VA: C2.1, C3.1, U1.3 (VI), U4.7 (+Vout)
/-15VA: C4.1, C5.2, U2.2 (VI), U4.5 (-Vout)
GNDS: C1.2, C4.2, C6.2, C10.2, D3.1 (K), D4.1 (K), D7.1 (K), J1.1, J2.5, J2.7, R1.2, U4.1 (-Vin), U5.2 (GND)
unnamed: D1.2 (A), Q1.1 (G), R1.1
unnamed: D3.2 (A), R3.2
unnamed: D4.2 (A), R4.2
unnamed: D5.2 (A), R5.2
unnamed: D6.1 (K), R6.2
unnamed: D7.2 (A), R7.2
unnamed: J1.2, Q1.2 (D)
VCOM: C2.2, C5.1, C7.2, C8.1, D5.1 (K), D6.2 (A), J2.2, U1.2 (GND), U2.1 (GND), U4.4 (COM)

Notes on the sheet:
Pin Assignments: ——————————— 1. Analog +12V 2. Isolated GND 3. Analog -12V 4. Fan +24V 5. Common GND 6. Digital +5V 7. Common GND PSU Module Nominal Current Usage: 65mA PSU Current Requirements: —————————————————— A) Analog +/-12V —> CurrentSinkModule: 30mA B) Digital +5V —> ControlModule: 100mA C)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
Input/Output Connectors
B) Microcontroller PSU
A) Analog PSU
Unregulated

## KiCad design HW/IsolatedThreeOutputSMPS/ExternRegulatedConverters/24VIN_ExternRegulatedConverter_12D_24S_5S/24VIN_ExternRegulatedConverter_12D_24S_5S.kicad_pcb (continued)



Board: 2 copper layers, 69.8 x 44.5 mm, 28 parts (11 on the bottom side), 15 nets.

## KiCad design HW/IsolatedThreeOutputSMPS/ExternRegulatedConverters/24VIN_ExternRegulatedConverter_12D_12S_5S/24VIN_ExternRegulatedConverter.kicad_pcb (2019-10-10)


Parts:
C1, C14: 4.7uF; CP_Elec_4x5.7
C2, C6, C7, C9: 330nF; C_0805_2012Metric_Pad1.15x1.40mm_HandSolder
C3: 33p; C_1206_3216Metric_Pad1.42x1.75mm_HandSolder
C4: 220p; C_1206_3216Metric_Pad1.42x1.75mm_HandSolder
C5: 100nF; CP_Elec_4x5.7
C8: 2.2uF; CP_Elec_4x5.7
C10, C11: 100nF; C_0805_2012Metric_Pad1.15x1.40mm_HandSolder
C12, C13: 1uF; CP_Elec_4x5.7
D1: BYS12-90-E3/TR; D_SMA_Handsoldering
D2: ES2G; D_SMA_Handsoldering
D3, D4, D5, D6, D7: LED; LED_D3.0mm
HS1: SK 480/50 SA; SK512_SK480_50MM
HS2, HS3: SK 481/50 SA; SK481_SK480_25MM
J1: 24VDC; PinHeader_1x02_P2.54mm_Horizontal
J2: Conn_01x07; Molex_KK-254_AE-6410-07A_1x07_P2.54mm_Vertical
L1: 1mH; L_Neosid_SM-NE127_HandSoldering
R3: 10K; R_1206_3216Metric_Pad1.42x1.75mm_HandSolder
R4: 6K8; R_1206_3216Metric_Pad1.42x1.75mm_HandSolder
R5, R6: 4K7; R_1206_3216Metric_Pad1.42x1.75mm_HandSolder
R7: 1K2; R_1206_3216Metric_Pad1.42x1.75mm_HandSolder
U1: ISE2409A-H; ISE
U2: LM7812_TO220; TO-220-3_Vertical
U3: LM7912_TO220; TO-220-3_Vertical
U4: R2D-2415; R2D
U5: LM7805_TO220; TO-220-3_Vertical
U6: L7818CV; TO-220-3_Vertical
U7: L78M15ABV; TO-220-3_Vertical

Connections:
+5V: C10.1, J2.6, R7.1, U5.3 (VO)
+12V: C11.1, J2.1, R5.1, U2.3 (VO)
+15V: C13.1, D2.1 (K), J2.4, R4.1, U7.3 (VO)
+24V: C1.1, C2.1, C3.2, C14.1, D1.1 (K), L1.1, R3.1, U4.2 (+Vin), U6.1 (VI)
-12V: C12.2, J2.3, R6.1, U3.3 (VO)
/+9V: C6.1, U1.5 (+Vout), U5.1 (VI)
/+15VA: C3.1, C7.1, U2.1 (VI), U4.7 (+Vout)
/+18V: C5.1, C9.1, U6.3 (VO), U7.1 (VI)
/-15VA: C4.1, C8.2, U3.2 (VI), U4.5 (-Vout)
GNDS: C1.2, C2.2, C4.2, C5.2, C6.2, C9.2, C10.2, C13.2, C14.2, D2.2 (A), D3.1 (K), D4.1 (K), D7.1 (K), J1.1, J2.5, J2.7, U1.1 (-Vin), U1.4 (0V), U4.1 (-Vin), U5.2 (GND), U6.2 (GND), U7.2 (GND)
unnamed: D1.2 (A), J1.2
unnamed: D3.2 (A), R3.2
unnamed: D4.2 (A), R4.2
unnamed: D5.2 (A), R5.2
unnamed: D6.1 (K), R6.2
unnamed: D7.2 (A), R7.2
unnamed: L1.2, U1.2 (+Vin)
VCOM: C7.2, C8.1, C11.2, C12.1, D5.1 (K), D6.2 (A), J2.2, U2.2 (GND), U3.1 (GND), U4.4 (COM)

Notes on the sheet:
Pin Assignments: ——————————— 1. Analog +12V 2. Isolated GND 3. Analog -12V 4. Fan +15V 5. Common GND 6. Digital +5V 7. Common GND PSU Module Nominal Current Usage: 65mA PSU Current Requirements: —————————————————— A) Analog +/-12V —> CurrentSinkModule: 30mA B) Digital +5V —> ControlModule: 100mA C)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
Input/Output Connectors
B) Microcontroller PSU
A) Analog PSU
C) Fan PSU
Unregulated
Thermal Spec: —————————— Amb: 30C 7818: 5K/W 7815: 3K/W SK481: 5.5K/W
Inductive Load Protection
Shared Between Analog/MCU regulators
U6 JC Power Dissipation: (24V-18V) * 0.7A = 4.2W U6 JC Temp: 5 * 4.2 = 21 degC HS2 Temp = 4.2 * 5.5 = 23.1 degC Total U6 Temp = 30 + 21C + 23.1 = 74 degC
U7 JC Power Dissipation: (18V-15V) * 0.7A = 2.1W U7 JC Temp: 3 * 2.1 = 6.3 degC HS3 Temp = 2.1 * 5.5 = 11.5 degC Total U7 Temp = 30 + 6.3C + 11.5 = 47.8 degC



Board: 2 copper layers, 85.1 x 50.8 mm, 39 parts (15 on the bottom side), 18 nets.

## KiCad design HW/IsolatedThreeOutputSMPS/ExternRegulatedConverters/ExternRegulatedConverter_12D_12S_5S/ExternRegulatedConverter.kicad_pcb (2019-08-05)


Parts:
C1: 2.2uF; CP_Elec_4x5.7
C2, C5, C7: 330nF; C_0805_2012Metric_Pad1.15x1.40mm_HandSolder
C3: 33p; C_1206_3216Metric_Pad1.42x1.75mm_HandSolder
C4: 220p; C_1206_3216Metric_Pad1.42x1.75mm_HandSolder
C6, C9, C10: 100nF; C_0805_2012Metric_Pad1.15x1.40mm_HandSolder
C8, C11: 10uF; CP_Elec_4x5.7
D1: D_Schottky; D_SMA_Handsoldering
HS1: Heatsink; Heatsink_SheetType_50x7mm_2Fixations
J1: 15VDC; Molex_KK-254_AE-6410-02A_1x02_P2.54mm_Vertical
J2: Conn_01x07; Molex_KK-254_AE-6410-07A_1x07_P2.54mm_Vertical
U1: RS6-1212D; ITX1212S
U2: LM7805_TO220; TO-220-3_Vertical
U3, U5: LM7812_TO220; TO-220-3_Vertical
U4: LM7912_TO220; TO-220-3_Vertical

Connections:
+5V: C9.1, J2.4, U2.3 (VO)
+12P: C6.1, J2.6, U5.3 (VO)
+12V: C10.1, J2.1, U3.3 (VO)
+15V: C1.1, C2.1, C3.2, C5.1, D1.1 (K), U1.2 (+Vin), U2.1 (VI), U5.1 (VI)
-12V: C11.2, J2.3, U4.3 (VO)
GNDA: C1.2, C2.2, C4.2, C5.2, C6.2, C9.2, J1.1, J2.5, J2.7, U1.1 (-Vin), U2.2 (GND), U5.2 (GND)
unnamed: C3.1, C7.1, U1.6 (+Vout), U3.1 (VI)
unnamed: C4.1, C8.2, U1.8 (-Vout), U4.2 (VI)
unnamed: D1.2 (A), J1.2
VCOM: C7.2, C8.1, C10.2, C11.1, J2.2, U1.7 (COM), U3.2 (GND), U4.1 (GND)



Board: 2 copper layers, 71.1 x 53.3 mm, 20 parts (8 on the bottom side), 10 nets.

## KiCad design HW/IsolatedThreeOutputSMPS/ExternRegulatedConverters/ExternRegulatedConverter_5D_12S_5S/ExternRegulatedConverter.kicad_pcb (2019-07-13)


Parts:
C1: 47p; C_Disc_D4.3mm_W1.9mm_P5.00mm
C2, C5: 200nF; C_Rect_L7.0mm_W2.0mm_P5.00mm
C3: 47p; C_Disc_D3.0mm_W2.0mm_P2.50mm
C6, C9: 100nF; C_Rect_L7.0mm_W2.0mm_P5.00mm
C10, C11: 4.7u; CP_Radial_D5.0mm_P2.50mm
D1: D_Schottky; D_DO-41_SOD81_P10.16mm_Horizontal
HS1: Heatsink; Heatsink_SheetType_50x7mm_2Fixations
J1: 15VDC; Molex_KK-254_AE-6410-02A_1x02_P2.54mm_Vertical
J_FANPWR1: Conn_01x02; Molex_KK-254_AE-6410-02A_1x02_P2.54mm_Vertical
J_MCUPWR1: Conn_01x02; Molex_KK-254_AE-6410-02A_1x02_P2.54mm_Vertical
J_OAPWR1, J_OAPWR2: Conn_01x03; Molex_KK-254_AE-6410-03A_1x03_P2.54mm_Vertical
L1, L2: 10u; L_Radial_D6.0mm_P4.00mm
U1: MEA1D1505DC; MEA1D
U2: LM7805_TO220; TO-220-3_Vertical
U5: LM7812_TO220; TO-220-3_Vertical

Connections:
+5V: C9.1, J_MCUPWR1.1, U2.3 (VO)
+5VA: C10.1, J_OAPWR1.1, J_OAPWR2.1, L1.2
+12V: C6.1, J_FANPWR1.1, U5.3 (VO)
+15V: C1.2, C2.1, C5.1, D1.1 (K), U1.14 (Vin+), U2.1 (VI), U5.1 (VI)
-5VA: C11.2, J_OAPWR1.3, J_OAPWR2.3, L2.2
GNDA: C2.2, C3.2, C5.2, C6.2, C9.2, J1.1, J_FANPWR1.2, J_MCUPWR1.2, U1.1 (Vin-), U2.2 (GND), U5.2 (GND)
unnamed: C1.1, L1.1, U1.9 (Vout+)
unnamed: C3.1, L2.1, U1.11 (Vout-)
unnamed: D1.2 (A), J1.2
VCOM: C10.2, C11.1, J_OAPWR1.2, J_OAPWR2.2, U1.8 (GND)


Board: 2 copper layers, 71.1 x 49.5 mm, 20 parts (0 on the bottom side), 10 nets.

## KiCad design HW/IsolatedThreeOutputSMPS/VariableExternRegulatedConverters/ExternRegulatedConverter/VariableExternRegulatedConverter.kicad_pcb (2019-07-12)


Board: 2 copper layers, 81.3 x 68.6 mm, 26 parts (0 on the bottom side), 15 nets.

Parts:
C1, C7, C8: 10uF; CP_Radial_D5.0mm_P2.50mm
C2: 200nF; C_Rect_L7.0mm_W2.0mm_P5.00mm
C3: 47p; C_Disc_D3.0mm_W1.6mm_P2.50mm
C4: 100p; C_Disc_D3.0mm_W1.6mm_P2.50mm
C5, C6, C9: 100nF; C_Rect_L7.0mm_W2.0mm_P5.00mm
C10, C11: 1uF; CP_Radial_D5.0mm_P2.50mm
D1: D_Schottky; D_DO-41_SOD81_P7.62mm_Horizontal
HS1: Heatsink; Heatsink_SheetType_50x7mm_2Fixations
J1: Conn_01x02; PinHeader_1x02_P2.54mm_Vertical
J2: Conn_01x05; PinHeader_1x05_P2.54mm_Vertical
L1: 10mH; Choke_Schaffner_RN204-04-9.0x14.0mm
R1, R4: 100R; R_Axial_DIN0207_L6.3mm_D2.5mm_P7.62mm_Horizontal
R2, R3: 1K5; R_Axial_DIN0207_L6.3mm_D2.5mm_P7.62mm_Horizontal
RV1, RV2: 1K; Potentiometer_Bourns_3296Y_Vertical
U1: RS6-1212D; ITX1212S
U2: LM7805_TO220; TO-220-3_Vertical
U3: LM317_3PinPackage; TO-220-3_Vertical
U4: LM337_TO220; TO-220-3_Vertical

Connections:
+5V: C9.1, J2.4, U2.3
+12V: C10.1, J2.1, RV1.3, U3.2
-12V: C11.2, J2.3, RV2.1, U4.3
GNDA: C1.2, C2.2, C9.2, J1.1, J2.5, L1.3, U2.2
unnamed: C3.1, C5.1, U1.6, U3.3
unnamed: C3.2, L1.2, U1.2
unnamed: C4.1, C6.2, U1.8, U4.2
unnamed: C4.2, L1.4, U1.1
unnamed: C7.1, R1.2, R2.1, U3.1
unnamed: C8.2, R3.2, R4.1, U4.1
unnamed: D1.2, J1.2
unnamed: R1.1, RV1.1, RV1.2
unnamed: R4.2, RV2.2, RV2.3
VCOM: C5.2, C6.1, C7.2, C8.1, C10.2, C11.1, J2.2, R2.2, R3.1, U1.7
VDD: C1.1, C2.1, D1.1, L1.1, U2.1

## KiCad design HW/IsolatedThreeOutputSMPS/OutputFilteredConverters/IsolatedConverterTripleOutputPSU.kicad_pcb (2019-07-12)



Board: 2 copper layers, 78.7 x 66.0 mm, 21 parts (2 on the bottom side), 14 nets.

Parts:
C1, C2, C3, C4: 10uF; CP_Radial_D5.0mm_P2.50mm
C5, C6, C7: 220uF; CP_Radial_D8.0mm_P5.00mm
C8: 47p; C_Disc_D5.0mm_W2.5mm_P5.00mm
C9: 100p; C_Disc_D5.0mm_W2.5mm_P5.00mm
D1: D_Schottky; D_DO-15_P2.54mm_Vertical_AnodeUp
J1: Conn_01x02; PinHeader_1x02_P2.54mm_Vertical
J2: Conn_01x08; PinSocket_1x08_P2.54mm_Vertical
L1: 1mH; Choke_Schaffner_RN212-04-12.5x18.0mm
L2: 1mH; L_Radial_D12.0mm_P5.00mm_Fastron_11P
L3: 200uH; L_Radial_D8.7mm_P5.00mm_Fastron_07HCP
L4: 100uH; L_Radial_D8.7mm_P5.00mm_Fastron_07HCP
L5, L6, L7: 10uH; L_Radial_D8.7mm_P5.00mm_Fastron_07HCP
U1: RS6-1212D; ITX1212S
U2: RS6-1205S; ITX1212S

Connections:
/+5V: C7.1, J2.8, L7.2
/+12V: C5.1, J2.1, L5.2
/-12V: C6.2, J2.3, L6.2
/COM: C5.2, C6.1, J2.2, U1.7
GNDS: C1.2, C2.2, C3.2, C4.2, C7.2, C9.2, J1.1, J2.7, L1.3, L1.4, U1.1, U2.1, U2.7
unnamed: C1.1, C3.1, D1.1, L1.1, L2.1
unnamed: C2.1, L1.2, L3.1
unnamed: C4.1, L2.2, L4.1
unnamed: C8.1, L5.1, U1.6
unnamed: C8.2, L3.2, U1.2
unnamed: C9.1, L6.1, U1.8
unnamed: D1.2, J1.2
unnamed: L4.2, U2.2
unnamed: L7.1, U2.6

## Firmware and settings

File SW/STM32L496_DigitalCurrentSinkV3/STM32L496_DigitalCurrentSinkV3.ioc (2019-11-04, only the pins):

Mcu.UserName=STM32L496VETx
PA1.Signal=ADCx_IN6
PA2.Signal=ADCx_IN7
PA4.Signal=COMP_DAC11_group
PA5.Signal=COMP_DAC12_group
PB0.GPIO_Label=KP5_EXTI0
PB0.Signal=GPXTI0
PB1.GPIO_Label=KP6_EXTI1
PB1.Signal=GPXTI1
PB2.GPIO_Label=KP7_EXTI2
PB2.Signal=GPXTI2
PB6.Signal=I2C1_SCL
PB7.Signal=I2C1_SDA
PC1.GPIO_Label=OLED_RST
PC1.Signal=GPIO_Output
PD10.GPIO_Label=Btn1_EXT10
PD10.Signal=GPXTI10
PD11.GPIO_Label=Btn2_EXT11
PD11.Signal=GPXTI11
PD12.GPIO_Label=Btn3_EXT12
PD12.Signal=GPXTI12
PD13.GPIO_Label=Btn4_EXT13
PD13.Signal=GPXTI13
PE10.GPIO_Label=KP4_GPOUT
PE10.Signal=GPIO_Output
PE7.GPIO_Label=KP1_GPOUT
PE7.Signal=GPIO_Output
PE8.GPIO_Label=KP2_GPOUT
PE8.Signal=GPIO_Output
PE9.GPIO_Label=KP3_GPOUT
PE9.Signal=GPIO_Output

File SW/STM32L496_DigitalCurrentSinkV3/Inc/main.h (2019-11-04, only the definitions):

#define OLED_RST_Pin GPIO_PIN_1
#define OLED_RST_GPIO_Port GPIOC
#define KP5_EXTI0_Pin GPIO_PIN_0
#define KP5_EXTI0_GPIO_Port GPIOB
#define KP5_EXTI0_EXTI_IRQn EXTI0_IRQn
#define KP6_EXTI1_Pin GPIO_PIN_1
#define KP6_EXTI1_GPIO_Port GPIOB
#define KP6_EXTI1_EXTI_IRQn EXTI1_IRQn
#define KP7_EXTI2_Pin GPIO_PIN_2
#define KP7_EXTI2_GPIO_Port GPIOB
#define KP7_EXTI2_EXTI_IRQn EXTI2_IRQn
#define KP1_GPOUT_Pin GPIO_PIN_7
#define KP1_GPOUT_GPIO_Port GPIOE
#define KP2_GPOUT_Pin GPIO_PIN_8
#define KP2_GPOUT_GPIO_Port GPIOE
#define KP3_GPOUT_Pin GPIO_PIN_9
#define KP3_GPOUT_GPIO_Port GPIOE
#define KP4_GPOUT_Pin GPIO_PIN_10
#define KP4_GPOUT_GPIO_Port GPIOE
#define Btn1_EXT10_Pin GPIO_PIN_10
#define Btn1_EXT10_GPIO_Port GPIOD
#define Btn1_EXT10_EXTI_IRQn EXTI15_10_IRQn
#define Btn2_EXT11_Pin GPIO_PIN_11
#define Btn2_EXT11_GPIO_Port GPIOD
#define Btn2_EXT11_EXTI_IRQn EXTI15_10_IRQn
#define Btn3_EXT12_Pin GPIO_PIN_12
#define Btn3_EXT12_GPIO_Port GPIOD
#define Btn3_EXT12_EXTI_IRQn EXTI15_10_IRQn
#define Btn4_EXT13_Pin GPIO_PIN_13
#define Btn4_EXT13_GPIO_Port GPIOD
#define Btn4_EXT13_EXTI_IRQn EXTI15_10_IRQn

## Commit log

2019-07-18 Updates
    - New simplified current sink design: see LTSpice model "MOSFET_CurrentSense_NoSignalInversion".
    Needs to be confirmed on breadboard!
    [ControlModule.kicad_pcb, CurrentSink.sch, CurrentSinkModule.kicad_pcb]
2019-07-18 - New simplified current sink design: see LTSpice model "MOSFET_CurrentSense_NoSignalInversion". Needs to be confirmed on breadboard!
2019-07-19 Finished CurrentSinkRevC layout
    [CurrentSink.sch, CurrentSinkModule.kicad_pcb, CurrentSinkModule.sch]
2019-07-21 Added Interafec IBOMS
    [Control.sch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]
2019-08-03 Created STM32L476 project
    [Control.sch]
2019-08-03 Tested SWO, I2C OLED and DAC (triangle outputs)
2019-08-03 debugged HW issue with EXTI buttons
    - Buttons required external pull-up resistors
    [Control.sch]
2019-08-03 updated software
    - Added DAC helper functions, including mode select, voltage and frequency increase
    - Unexplained noise present on DAC channel 1. Suddenly appeared without explanation. Confirmed code and settings. Chip might need replacing.
    [STM32L476_DigitalCurrentSinkV3.ioc, main.c, utils.c]
2019-08-04 updated SW
    - Tested OLED with shorter molex kk254 connector
    - Added screen overlay w/ data
    - Added DAC functions to calculate DAC output voltage and timer freq
    [ControlModule.kicad_pcb]
2019-08-05 updated hw
    - finished layout for power supply
    [ExternRegulatedConverter.kicad_pcb, ExternRegulatedConverter.sch, PowerFlags.sch]
2019-08-05 updated HW
    - ExternRegulatedConverter_12D_12S_5S layout optimised for etching
    [ExternRegulatedConverter.kicad_pcb, ExternRegulatedConverter.sch]
2019-08-05 updated SW
    - Enabled EXTI for keypad, only printf to SWD console
    - Added statemachine for display. Navigate to main/mode/value screens via top menu/tactile buttons
2019-08-12 current module hw update
    - Deleted opamp Bypass jumpers in schematic; they break opamp configurations
    - Added bypass instructions in schematic for each opamp.
    [CurrentSink.sch, CurrentSinkModule.kicad_pcb]
2019-08-13 updated SW
    - Added preview for setting volts/hertz via keypad and nudge controls, previewed value is applied using "SET" menu button or cancelled using "EXIT" menu button
    - TODO add decimal point support for entered value
2019-08-13 updated SW
    - Added debug for new value settings (implemented timer15 to wait 1-3 cycles for DAC conversion to complete)
2019-08-15 updated SW
    - Tested HW with ADC enabled. Basic SWDIO debug data received (with unexpected 200mV offset)
    [Control.sch]
2019-08-18 Tested RevC LTC3260 fixes
    - updated passive LTC3260 component values
    [CurrentSinkModule.kicad_pcb]
2019-08-19 added notes to current sink module schematic
    [CurrentSink.sch]
2019-08-19 Tested Contrl Module ADC input filter. Updated schematic for removing >1MHz noise.
    [Control.sch]
2019-08-20 updated SW
    - Added single and dual DAC voltage set functionality
2019-08-20 software update
    - Fixed some bugs in the UI code
    [DacUtilities.c, DisplayManager.c, InputManager.c]
2019-08-20 updated SW
    - Added single/dual reset and nudge adjust function
    [DacUtilities.c, DisplayManager.c, InputManager.c]
2019-08-21 migrated HW
    - Changed STM32L476 to STM32L496 (STM32L476 did not support ADC->DFSDM config)
    - Created new SW project "STM32L496_DigitalCurrentSinkV3"
    - Confirmed compilation success with all libs and firmware.
    [Control.sch]
2019-08-22 Tested STM32L496VG upgrade, replaced symbol in schematic
    [Control.sch]
2019-08-23 software update
    - Moved I2C HAL_Delay to after DAC init, minimizes any current surge on DUT
2019-08-24 Configured ADC->DFSDM HW filter
2019-08-24 Disabled DFSDM filter and rolled back to ADC DMA w/ oversampling
2019-08-25 updated sw
    - Added functions
    to adjust amp input to voltage DAC output. to amps output
2019-08-25 sw update
    Added functions to:
    - Convert amps user input to DAC voltage output
    - ADC voltage input to OLED display amps output
    - Added gain compensation for ADC input. Alt could be to increase INAMP gain resistor?
2019-08-26 updated sw
    - Added noise/random user amplitude selection function
    - Added 3x5 font.
    [DacUtilities.c, DisplayManager.c, InputManager.c]
2019-08-26 updated sw
    - Added seperate timer prescaler for slower freq when using RAND mode.
    - Fixed fonts and display issues
    [DacUtilities.c, DisplayManager.c, InputManager.c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]
2019-08-26 updated sw
    - Fixed decimal point display issues. Decimal point is displayed when DP button is pressed as opposed to only after 1st decimal place is entered.
    - Fixed truncation issues when calculating volts (float) from bits.
    [DacUtilities.c, DisplayManager.c, InputManager.c]
2019-08-28 updated sw
    - fixed bug where CH2 auto mode amplitude could not be set. On startup.
    [InputManager.c]
2019-08-30 updated SW
    - Adjusted INAMP_GAIN_COMP
    - Added functions to
    - Limit input amps to 3A
    - Limit AUTO and RANDOM modes to 3A
    - Execute full reset (DU_FullReset)
    - AU_CalcCurrent will call DU_FullReset if current exceeds 3A
    [ADCUtilities.c, DacUtilities.c, DisplayManager.c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]
2019-08-31 updates
    - Replaced steel M3 busbar with lower resistance 9AWG copper conduit cable
    - Adjusted system constants to correct for above changes in resistance.
    [ADCUtilities.c, InputManager.c, SystemConstants.h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]
2019-09-10 added front panel design
    [Control.sch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]
2019-09-20 updated power supply and front panel
    [Control.sch, ControlModuleFrontPanel.kicad_pcb, ExternRegulatedConverter.kicad_pcb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]
2019-09-21 added 24V PSU
    [Control.sch, ControlModule.kicad_pcb, ControlModule.sch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]
2019-09-22 updated currentsink schematic
2019-09-22 expanded display aperture on front panel
    [ControlModuleFrontPanel.kicad_pcb]
2019-09-23 RevA layout PSU
    [ExternRegulatedConverter.kicad_pcb, ExternRegulatedConverter.sch, PowerFlags.sch]
2019-09-23 updated RevA SMPS layout
    [ExternRegulatedConverter.kicad_pcb, ExternRegulatedConverter.sch]
2019-09-23 updated layout
    [ExternRegulatedConverter.kicad_pcb]
2019-10-10 UPDATED 24VIN_PSU
    - Added 5V DC2DC input inductor (1mH)
    - Added 3mm THT LEDs for output rail status
    [24VIN_ExternRegulatedConverter.kicad_pcb, 24VIN_ExternRegulatedConverter.sch, ExternRegulatedConverter.kicad_pcb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]
2019-10-13 updated sw
    - Upgraded MOSFETS to IXFK50N85X/IXTK90P20P
    - Recalibrated firmware
2019-10-29 updated HW
    - Created 24VIN_ExternRegulatedConverter_12D_24S_5S
    [24VIN_ExternRegulatedConverter_12D_24S_5S.kicad_pcb, 24VIN_ExternRegulatedConverter_12D_24S_5S.sch, PowerFlags.sch]
2019-11-17 updated HW
    - Added front panel NRST switch
    - Changed 0402 to 0805 input filter, added NC jumper
    [Control.sch, ControlModule.kicad_pcb]

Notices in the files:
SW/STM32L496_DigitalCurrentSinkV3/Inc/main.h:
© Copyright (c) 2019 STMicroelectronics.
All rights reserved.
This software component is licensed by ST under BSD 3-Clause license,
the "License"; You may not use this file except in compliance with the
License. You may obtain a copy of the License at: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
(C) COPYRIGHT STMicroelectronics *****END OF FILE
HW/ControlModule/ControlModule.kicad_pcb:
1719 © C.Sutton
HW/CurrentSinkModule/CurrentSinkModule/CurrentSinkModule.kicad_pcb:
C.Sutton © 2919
